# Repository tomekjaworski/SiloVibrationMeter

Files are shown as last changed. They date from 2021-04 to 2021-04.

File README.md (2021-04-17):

# SiloVibrationMeter
Urządzenie do pomiaru wibracji powierzchniowych konstrukcji silosów

Urządzenie przeznaczone jest do pomiarów wibracji powierzchni silosów w konstrukcjach stalowych. Wibracje mierzone są w trzech osiach, za pomocą akcelerometrów i przekazywane do centralnego komputera.
Za kanał komunikacyjny wybrano UDP.

### Charakterystyka
  * Podstawa pomiarowa: trzy akcelerometry **ADXL001**, zasilanymi ze źródłeł napięcia referencyjnego **ADR3433ARJZ**.
  * Budowa jednego toru pomiarowego: programowalne źródło napięcia odniesienia **MCP4921** dla wzmacniacza Rail-to-Rail **MCP6S2** + **dwa** wspólne napięcia referencyjne (**REF02**).
  * Jednostka centralna: **dsPIC33FJ128MC706A** (16bit, architektura MIPS).
  * Komunikacja: kontroler ethernetowy **ENC28J60** z wbudowanym transformatorem separującym. Prędkośc komunikacji: **10Mbps**.
  * Obsługiwane protokoły: **UDP**, **IP**, **ARP**, **DHCP**, **ICMP**.
  * Metoda akwizycji danych: typu **Ping-Pong**, wykorzystująca wbudowany kontroler **DMA** (równoległa budowa nowej paczki pomiarów i wysyłanie już wcześniej zbudowane).

### Zdjęcia

Widok głównego okna aplikacji zbierającej dane z wielu urządzeń pomiarowych:
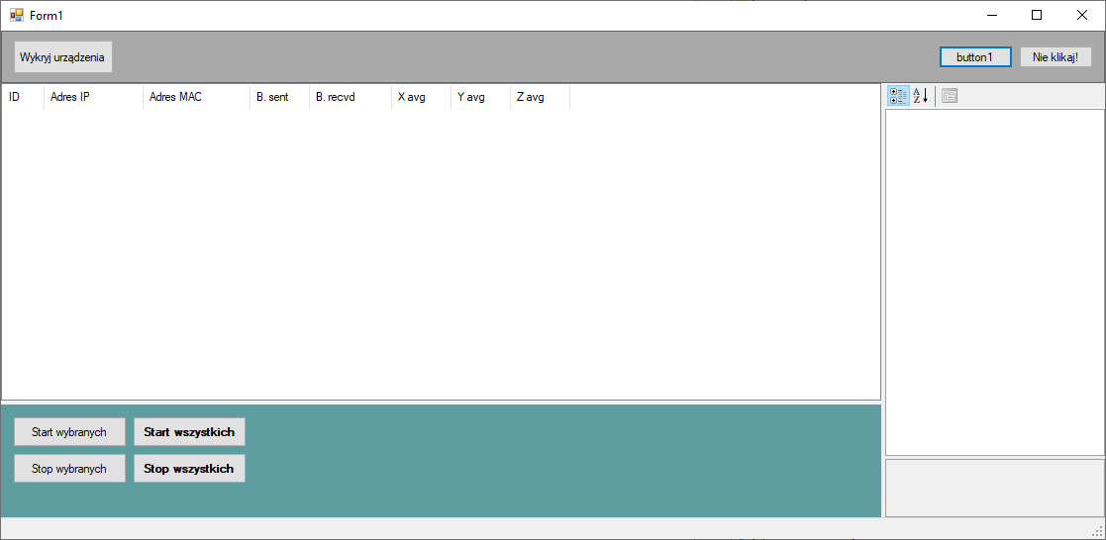
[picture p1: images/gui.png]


Prototyp pierwszy:
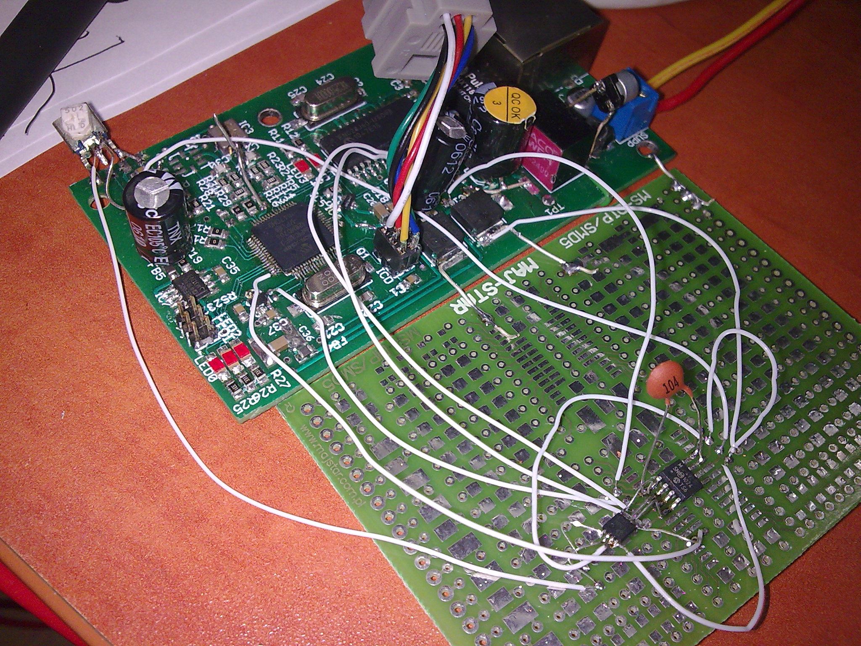
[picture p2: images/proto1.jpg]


Prototyp drugi:
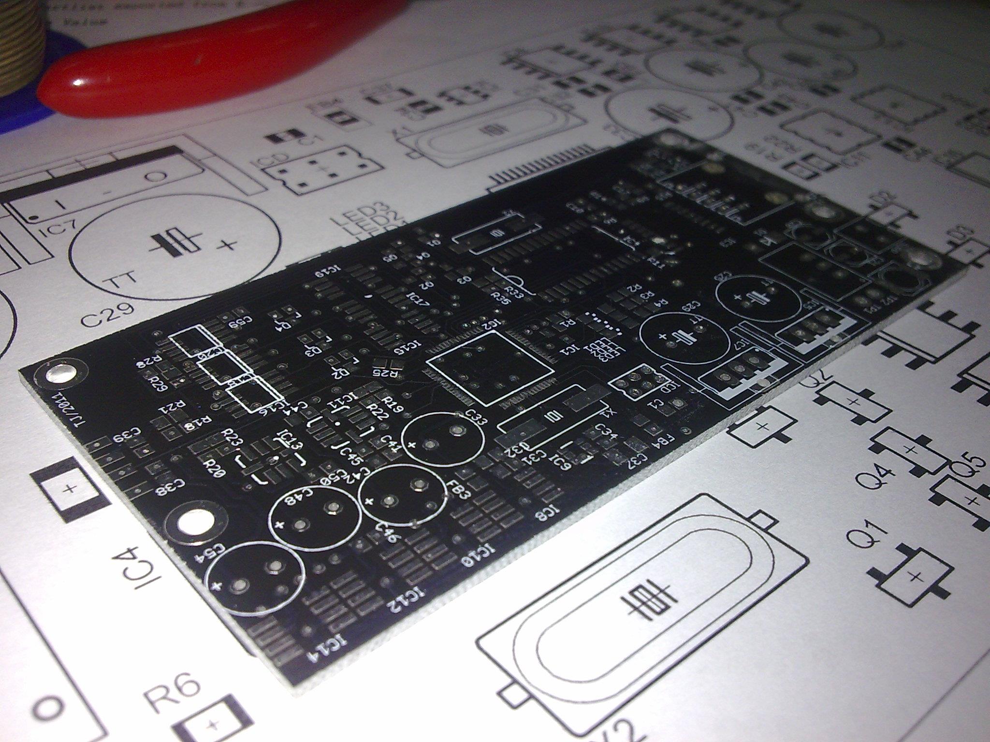
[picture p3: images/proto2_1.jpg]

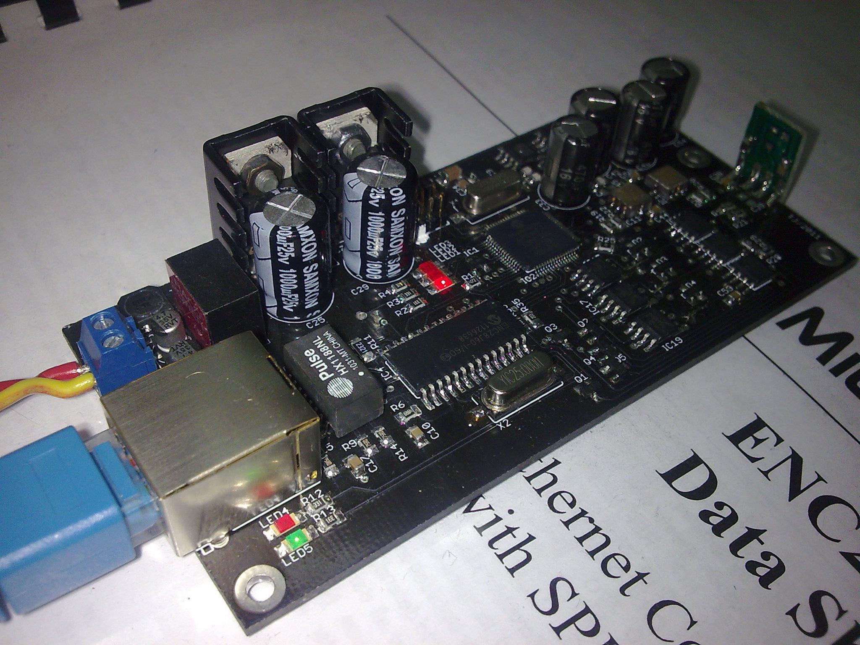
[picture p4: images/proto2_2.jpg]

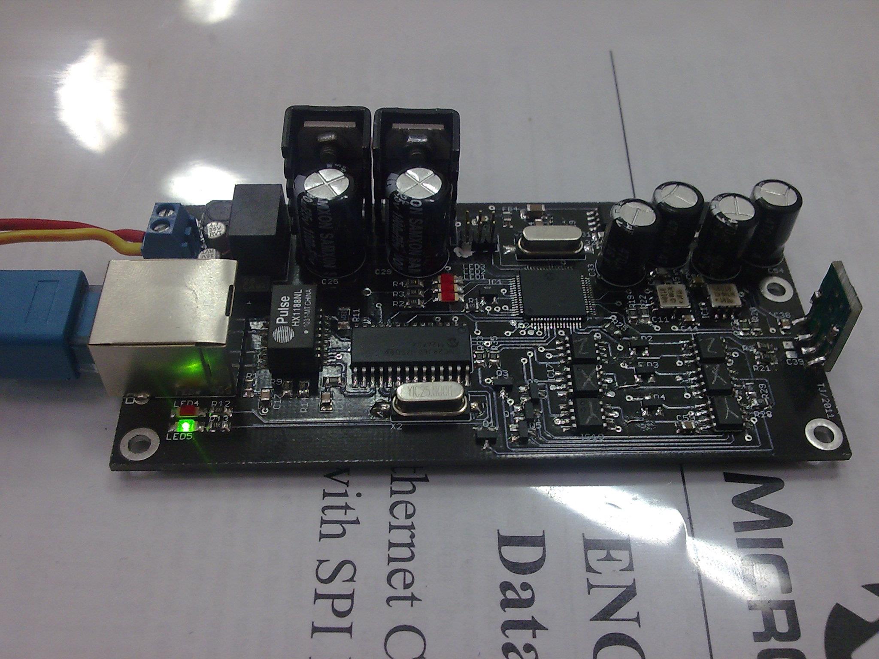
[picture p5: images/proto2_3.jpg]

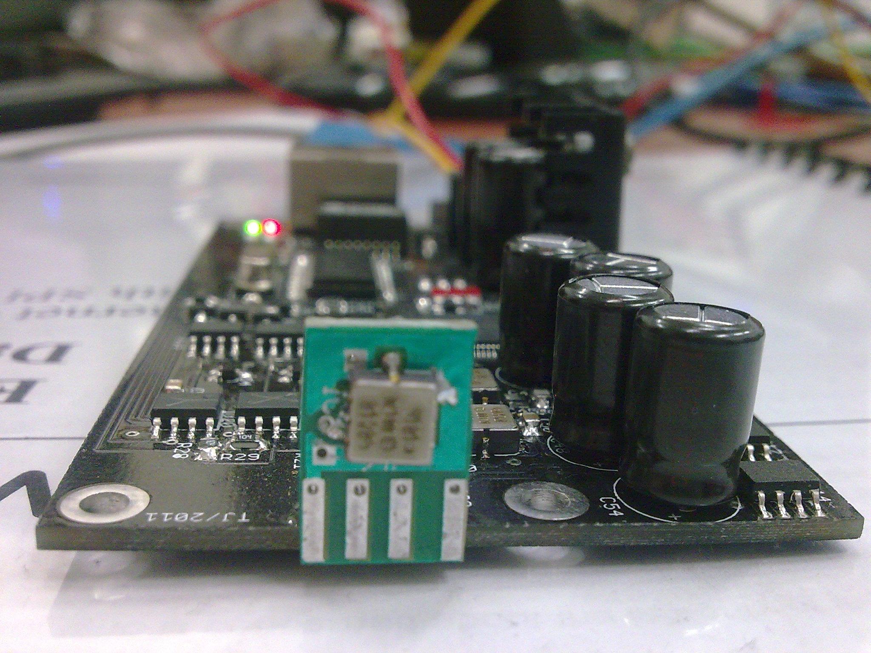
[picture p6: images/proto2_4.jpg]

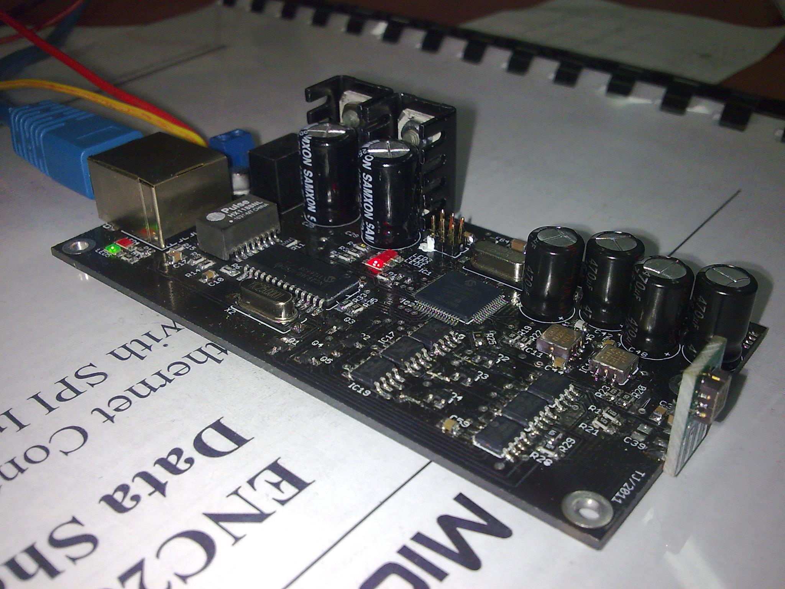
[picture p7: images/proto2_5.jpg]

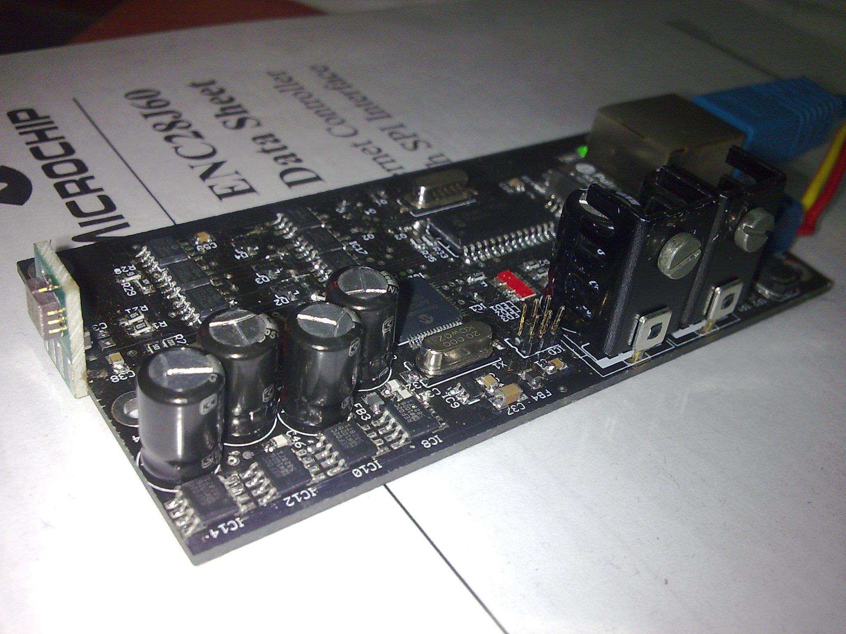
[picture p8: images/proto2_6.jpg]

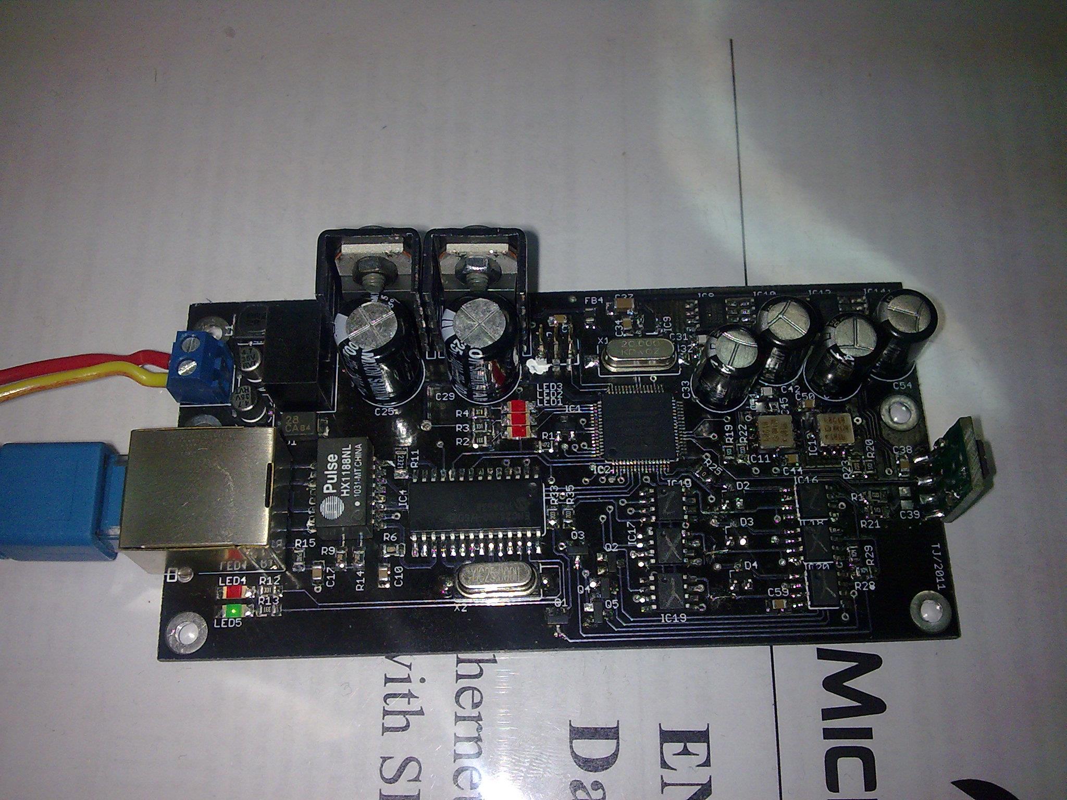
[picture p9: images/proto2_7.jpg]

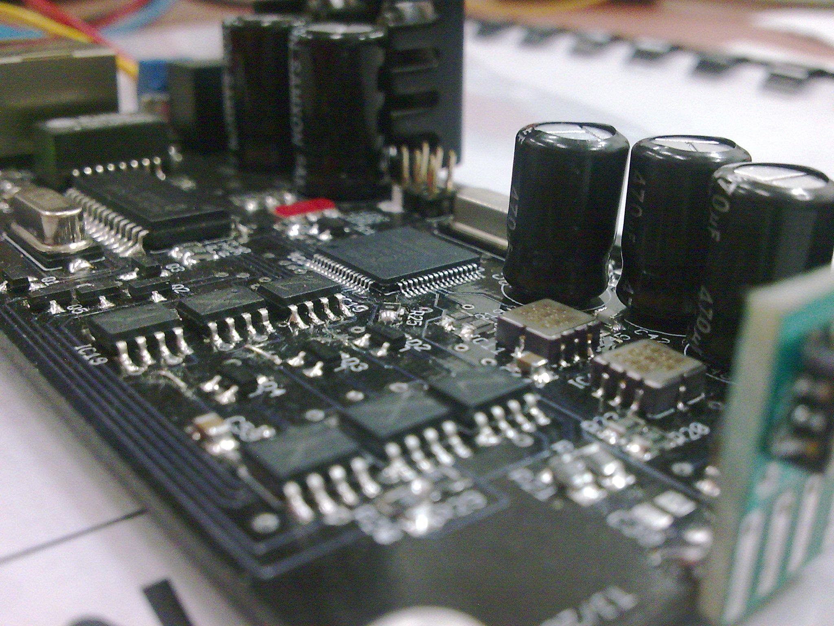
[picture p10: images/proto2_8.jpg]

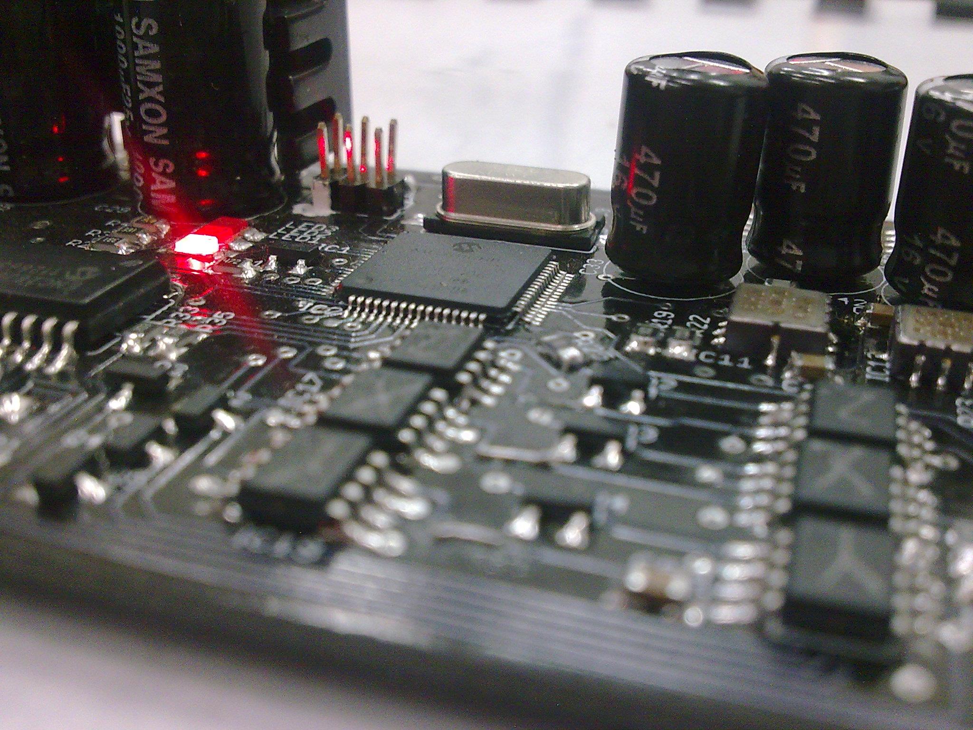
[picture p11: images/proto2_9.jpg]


Os pionowa:
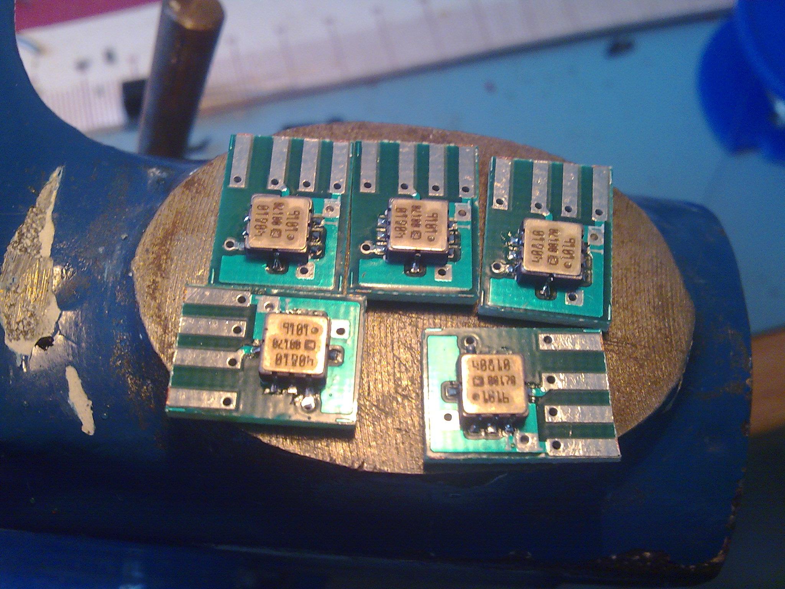
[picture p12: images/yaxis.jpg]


Testy prototypu drugiego:
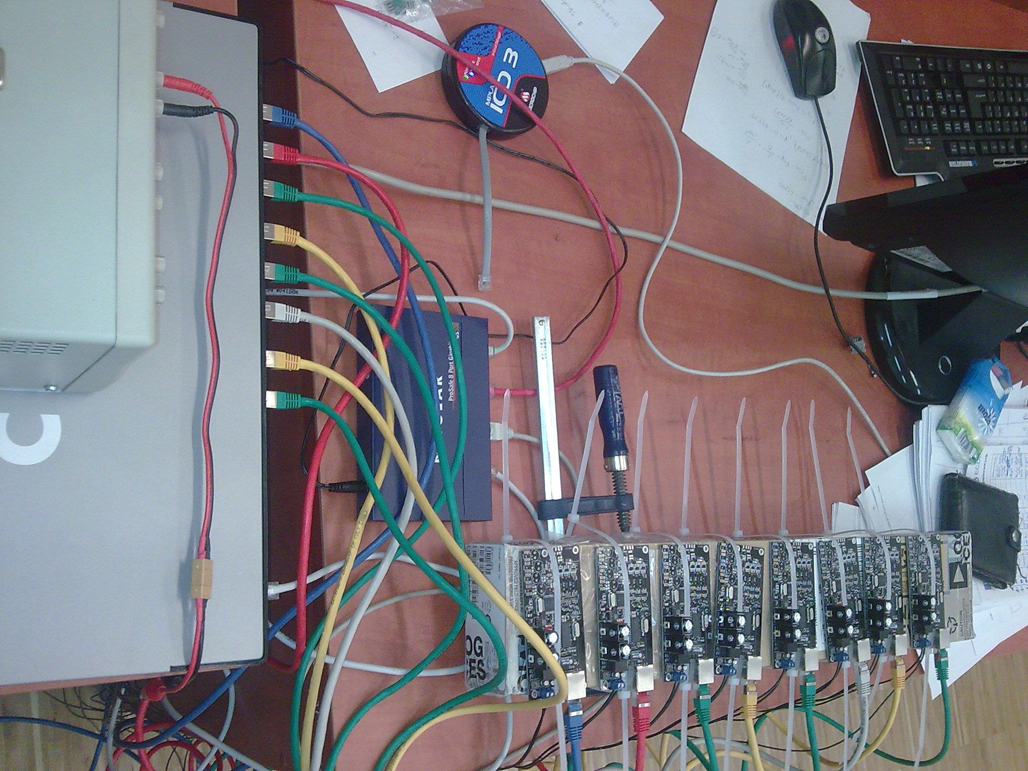
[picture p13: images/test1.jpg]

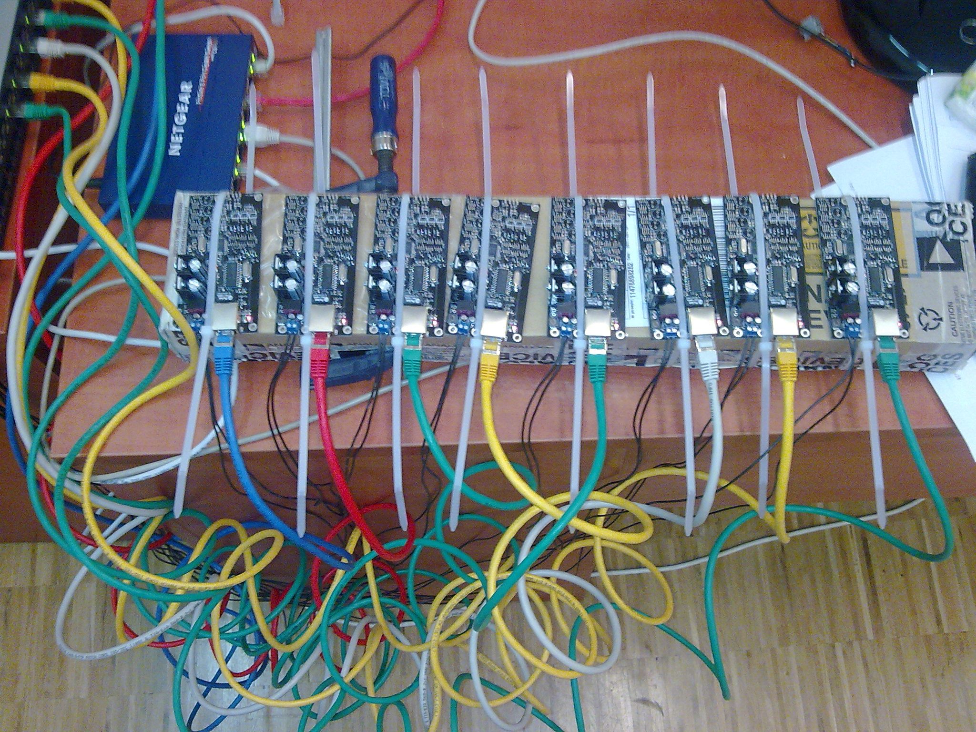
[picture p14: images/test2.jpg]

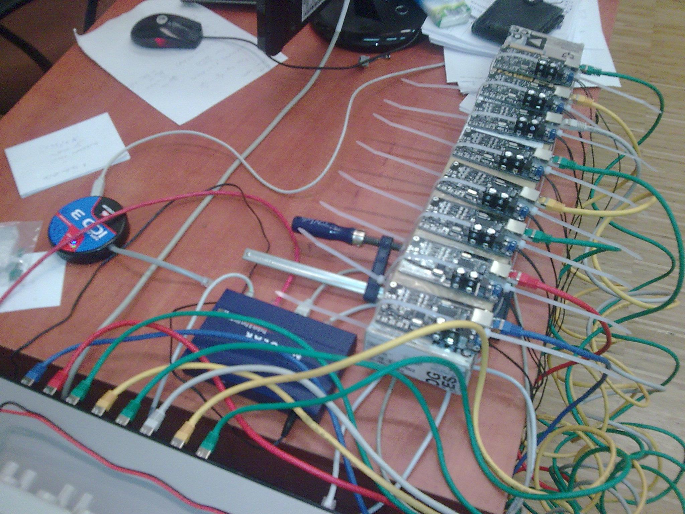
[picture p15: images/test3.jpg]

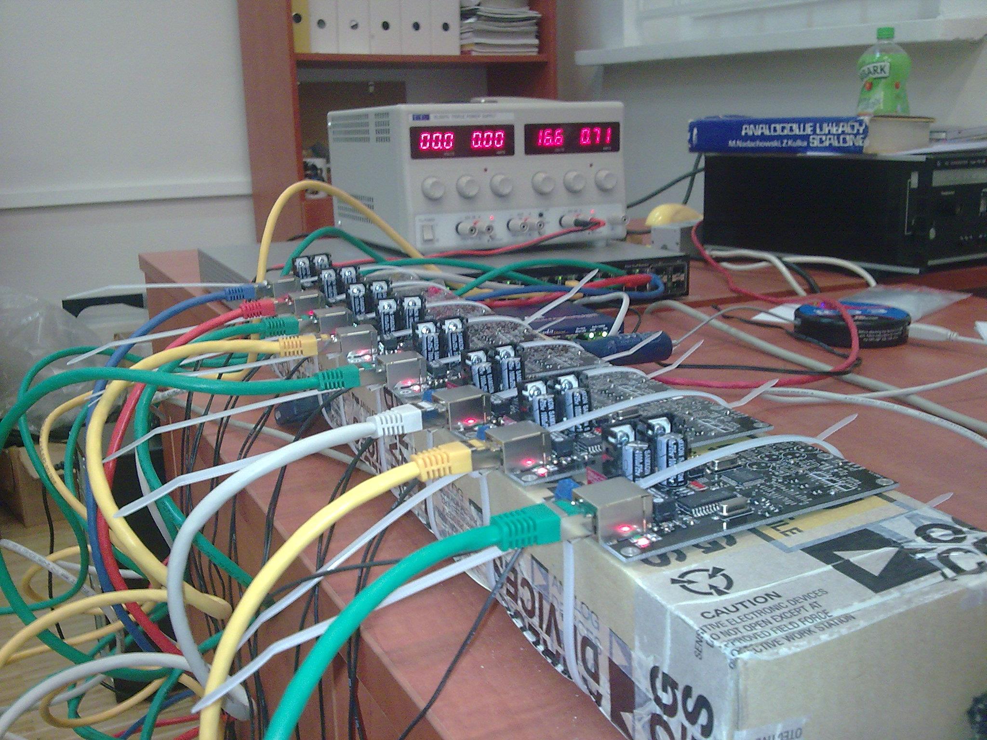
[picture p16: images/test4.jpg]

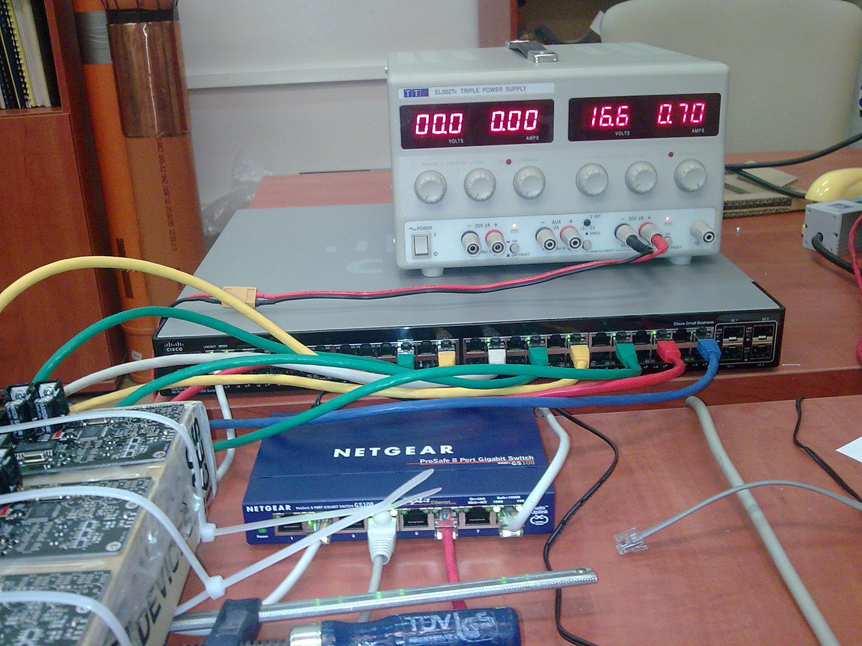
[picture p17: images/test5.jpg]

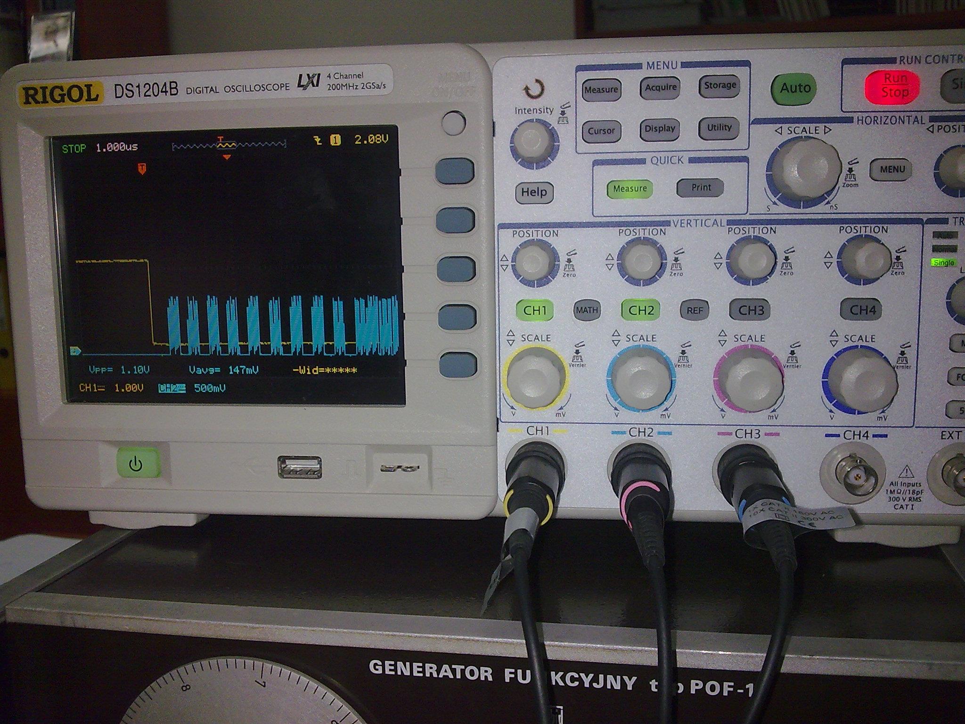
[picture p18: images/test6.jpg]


Ustawienia bitów w środowisku MPLAB:
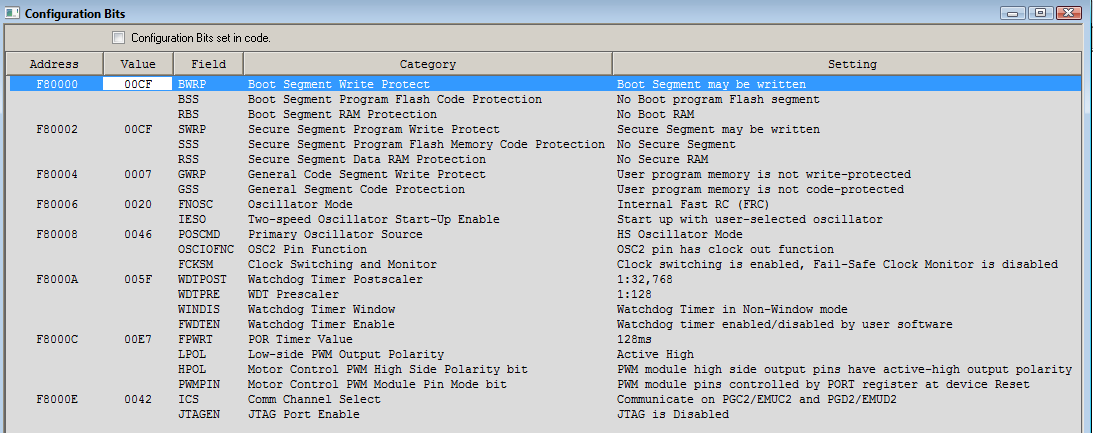
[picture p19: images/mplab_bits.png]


### Schematy
Blok CPU:
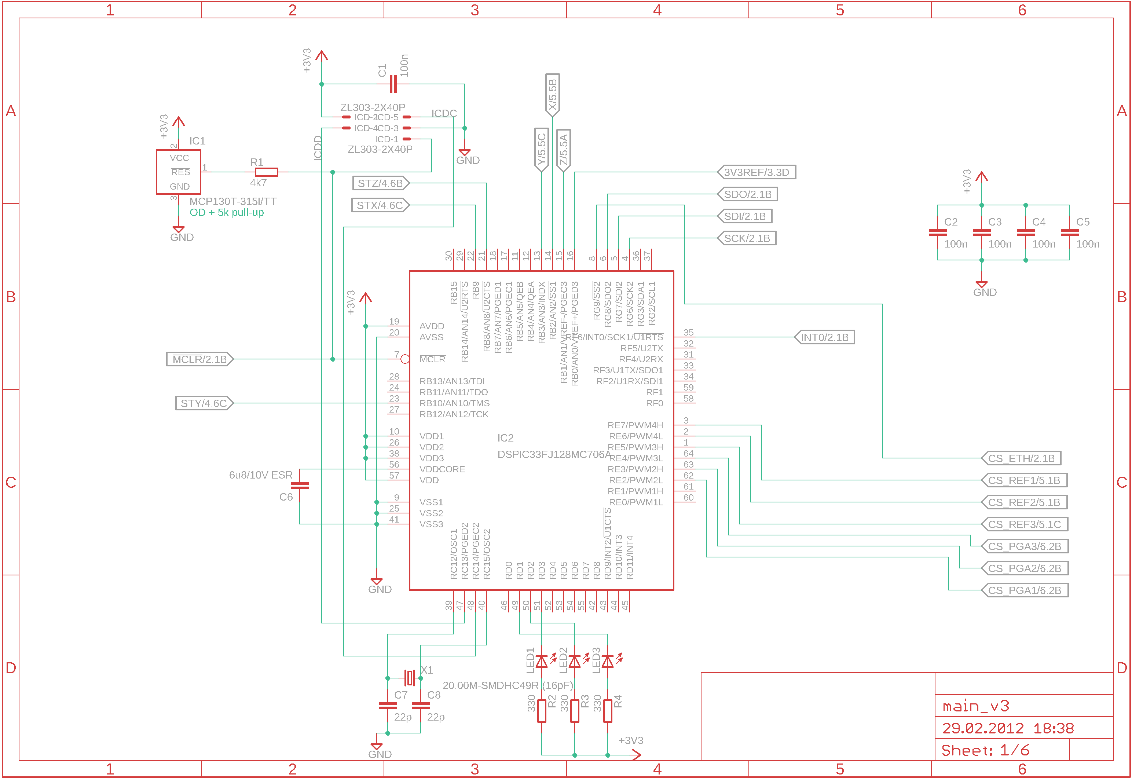
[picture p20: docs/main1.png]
Blok CPU

Interfejs sieciowy:
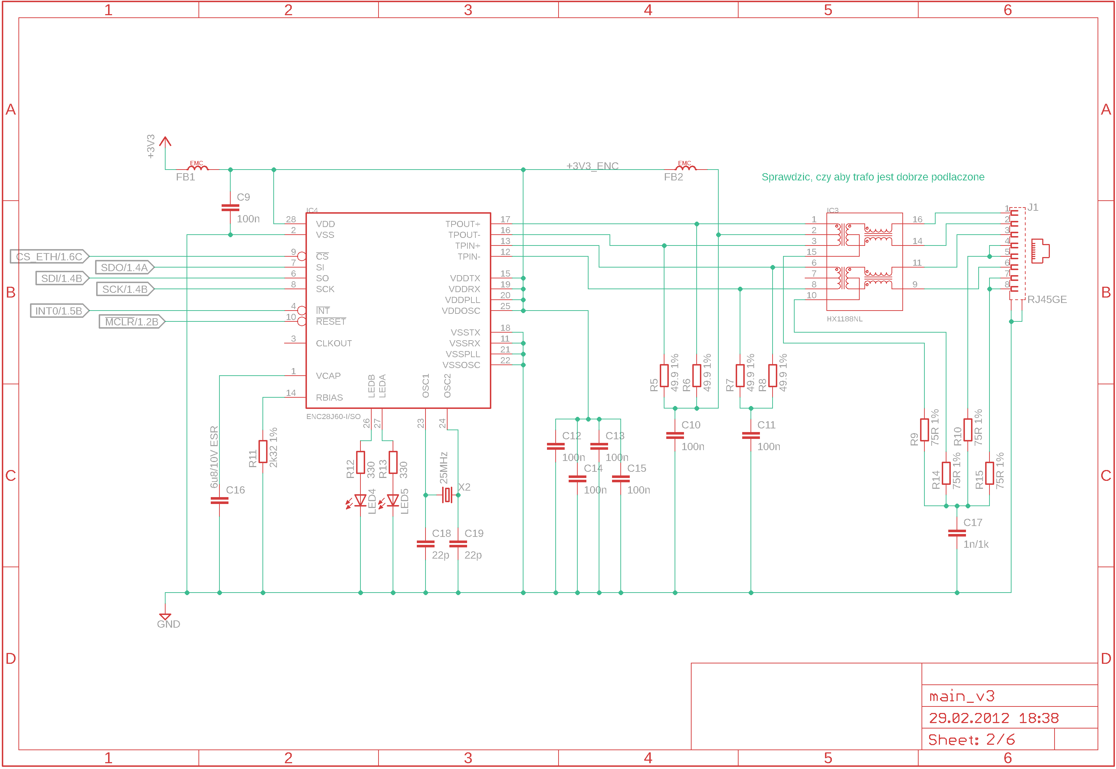
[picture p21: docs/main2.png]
Interfejs sieciowy

Zasilanie:
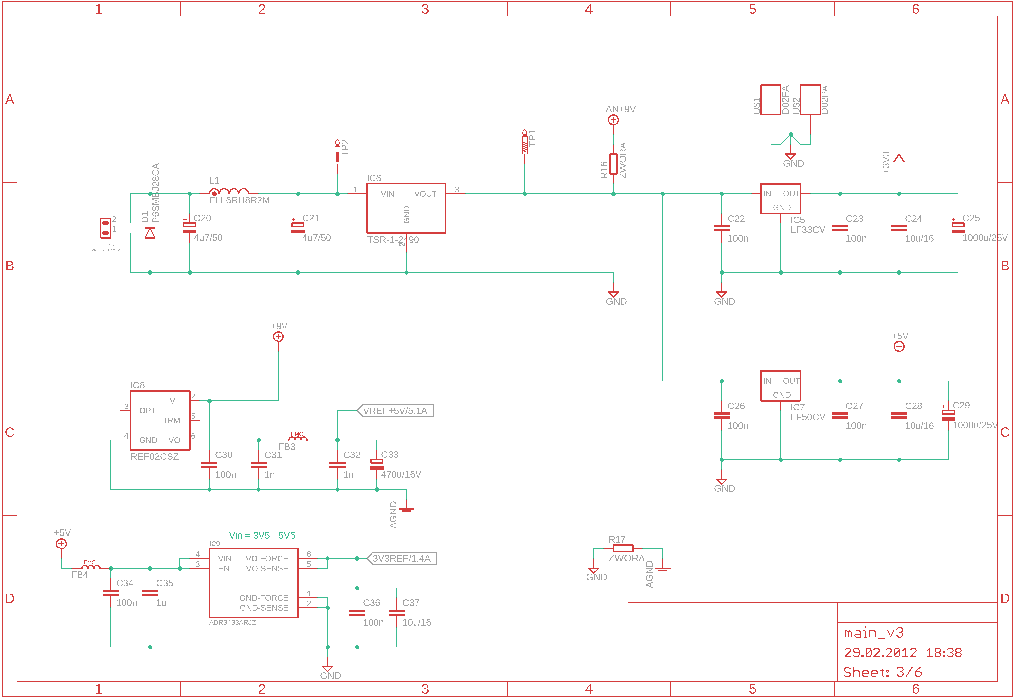
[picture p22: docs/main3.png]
Zasilanie

Akcelerometry i napięcie referencyjne:
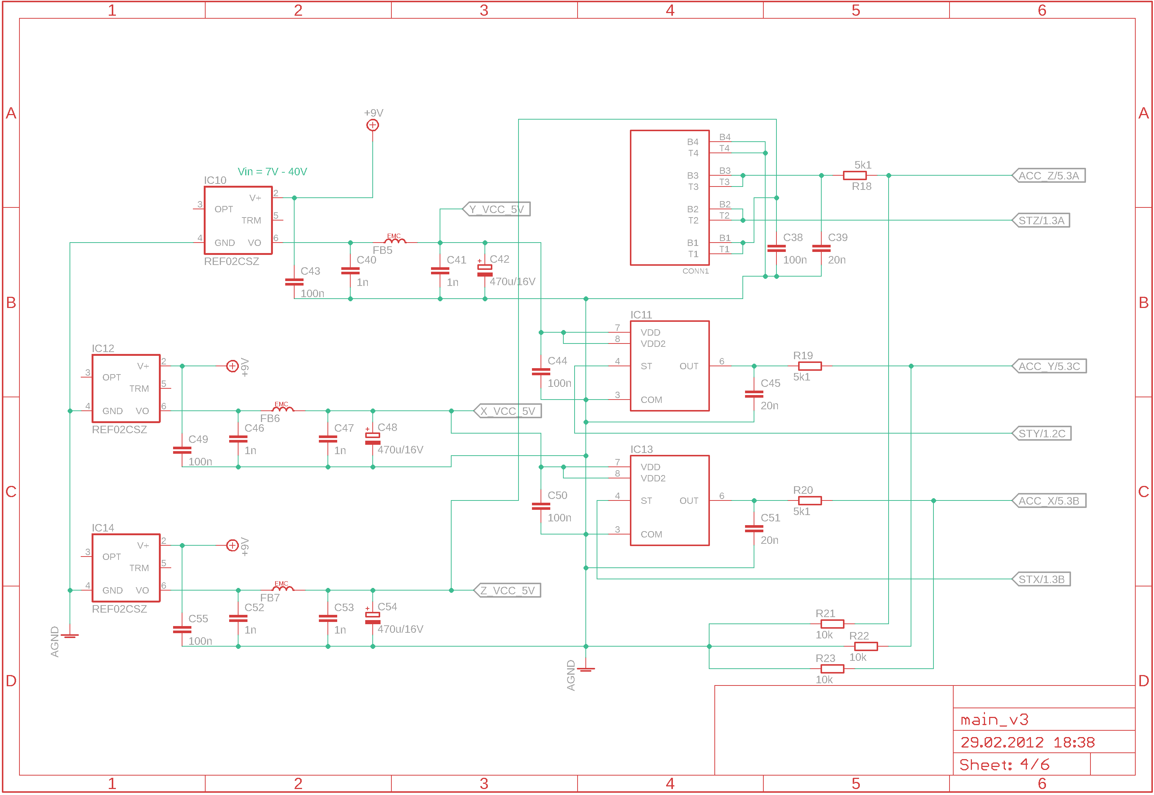
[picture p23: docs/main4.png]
Akcelerometry i napięcie referencyjne

Programowalne wzmacniacze:
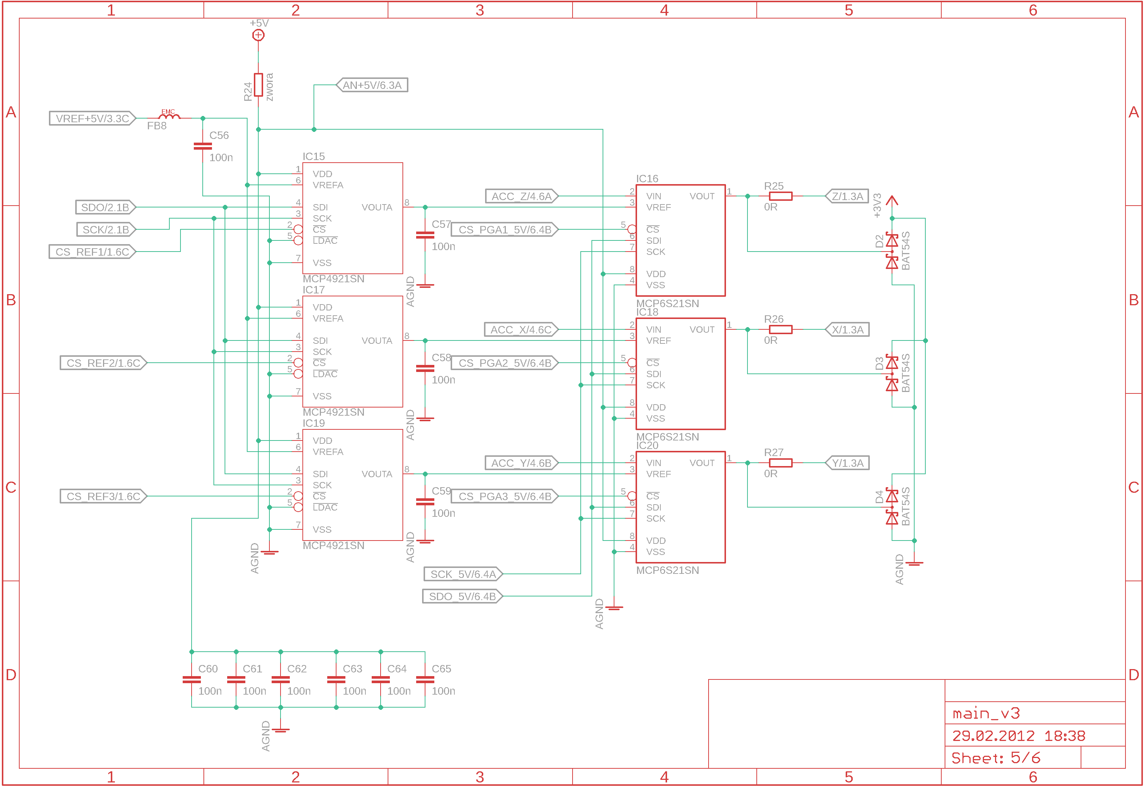
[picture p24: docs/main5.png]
Programowalne wzmacniacze

Konwerter poziomów 3V3 -> 5V:
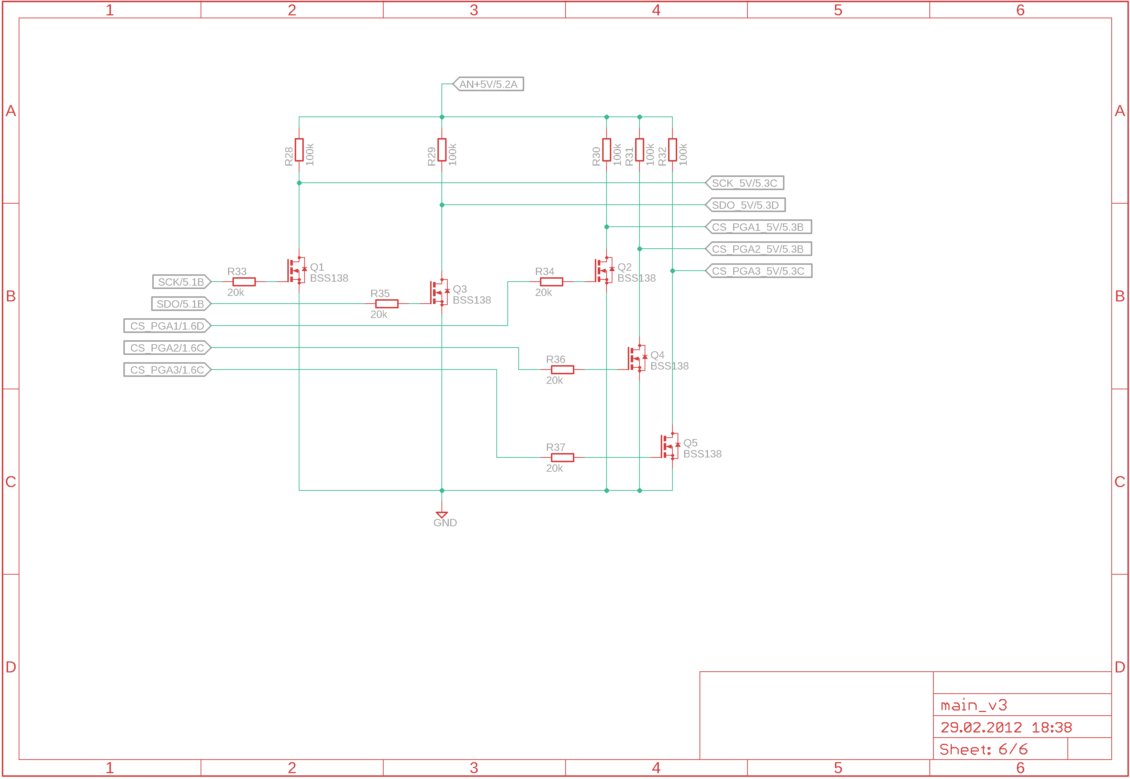
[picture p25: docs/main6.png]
Konwerter


Wersje PDF:
  * [Płyta główna - schemat](main_schemat.pdf)
  * [Płyta główna - PCB](docs/main_PCB.pdf)
  * [Moduł osi Z - schemat](osZ_inv.pdf)
  * [Moduł osi Z - PCB](osZ_inv_PCB.pdf )

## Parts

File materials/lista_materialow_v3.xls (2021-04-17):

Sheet: Arkusz1
Pozostało do zamówienia: | Zakupiono | miejsce | nazwa katalogowa | obudowa
0 | 12 | TME | P6SMBJ28CA | DO214AA | Dioda transil; 28V; 34,5V; 600W; dwukierunkowa; DO214AA
0 | 100 | TME | LCBB-601 | 0805 | Dławik:ferrytowy; Ferryt:koralik; 600R; 2A; SMD; 0805; R:100mΩ
0 | 400 | TME | CL21B104KBCNNNC | 0805 | Kondensator:ceramiczny; 100nF; 50V; X7R; ±10%; SMD; 0805; -55÷125°C
36 | 0 | TME | CSMD10U1206X | 1206 | Kondensator:ceramiczny; 10uF; 25V; X5R; ±10%; SMD; 1206
0 | 200 | TME | C0805C102J5GAC | 0805 | Kondensator:ceramiczny; 1nF; 50V; C0G (NP0); ±5%; SMD; 0805
0 | 100 | TME | C0805C105K8RAC | 0805 | Kondensator:ceramiczny; 1uF; 10V; X7R; ±10%; SMD; 0805; -55÷125°C
0 | 100 | TME | CL21C220JBANNNC | 0805 | Kondensator:ceramiczny; 22pF; 50V; C0G; ±5%; SMD; 0805; -55÷125°C
0 | 25 | TME | CE4.7/35-SMDHT |  | Kondensator:elektrolityczny; SMD; 4,7uF; 35V; Ø4x5,8mm; ±20%
0 | 25 | TME | TPSB685K016R120 | 1210 | Kondensator:tantalowy; 6,8uF; 16V; Obud:B; ESR:1200mΩ; ±10%; SMD
0 | 40 | TME | KPT-3216ID | 1206 | LED SMD; 1206; czerwony; 5-12mcd; 120°
0 | 30 | TME | KPT-3216SGD | 1206 | LED SMD; 1206; zielony; 3-12mcd; 120°
0 | 12 | TME | 33FJ128M706AIPT | TQFP64 | Mikrokontroler dsPIC; Pamięć programu:128kB; SRAM:16384B
0 | 12 | TME | 25.00M-SMDHC49S | SMD | Rezonator:kwarcowy; SMD; 25MHz
0 | 12 | TME | 20.00M-SMDHC49R | SMD | Rezonator:kwarcowy; SMD; Obud:HC49SM; 20MHz; Tolerancja:±30ppm
0 | 100 | TME | M0.6W-2K32 | THT | Rezystor:metal film; THT; 2,32kΩ; 0,6W; ±1%; Ø2,5x6,8mm; 50ppm/°C
72 | 0 | TME | SMD0805-0R | 0805 | Rezystor:thick film; SMD; 0805; 0R; 0,125W; ±5%; -55°C÷125°C
0 | 100 | TME | SMD0805-330R | 0805 | Rezystor:thick film; SMD; 0805; 330R; 0,125W; ±5%; -55÷125°C
0 | 100 | TME | SMD0805-4K7 | 0805 | Rezystor:thick film; SMD; 0805; 4,7kΩ; 0,125W; ±5%; -55°C÷125°C
48 | 0 | TME | SMD0805-75R-1% | 0805 | Rezystor:thick film; SMD; 0805; 75R; 0,125W; ±1%; -55°C÷125°C
0 | 100 | TME | SMD0805-49R9-1% | 0805 | Rezystor:thick film; SMD; 0805; 49,9R; 0,125W; ±1%; -55÷125°C
0 | 12 | TME | LF33CV | TO220 | Stabilizator napięcia:LDO,nieregulowany; 500mA; 3,3V; TO220
0 | 12 | TME | LF50CV | TO220 | Stabilizator napięcia:LDO,nieregulowany; 1000mA; 5V; TO220
0 | 12 | TME | HX1188NL |  | Transformator:LAN; SMD; -1dB; Przekładnia:RX 1:1,TX 1:1
0 | 12 | TME | MCP130T-315I/TT | SOT23 | Układ nadzorujący; open-drain; 3,15 V; Aktywny stan:niski; SOT23
0 | 12 | TME | ENC28J60-I/SO | SO28 | Układ scalony:kontroler ethernet; 10Base-T; SPI; SO28
0 | 48 | TME | REF02CSZ | SO8 | Źródło napięcia odniesienia; 5V; ±0,1% 8ppm; Montaż:SMD; SO8
27 | 21 | TME | KM470/16 | THT | Kondensator:elektrolityczny; THT; 470uF; 16V; Ø8x12mm; ±20%; 1000h
0 | 24 | TME | KM1000/25 | THT | Kondensator:elektrolityczny; THT; 1000uF; 25V; Ø10x16mm; ±20%
0 | 36 | TME | MCP4921-E/SN | SOIC8 | Przetwornik:D/A; 12bit; Kanały:1; SOIC8
23 | 13 | TME | MCP6S21-I/SN | SOIC8 | Układ scalony:wzmacniacz operacyjny; 2÷12MHz; SOIC8
0 | 24 | TME | D02PA | THT | Radiator:prasowany; U; TO202,TO220; 22K/W; czerniony; H:9,53mm
0 | 60 | TME | BSS138 | SOT23 | Tranzystor:unipolarny,N-MOSFET; 50V; 200mA; 360mW; SOT23
0 | 50 | TME | BAT54S | SOT23 | Dioda przełączająca Schottky; 30V; 10mA; 5ns; podwójna szeregowa
0 | 100 | TME | HP05-20K5% | 0805 | Rezystor:thick film; SMD; 0805; 20kΩ; 0,3W; ±5%; -55÷155°C
0 | 100 | TME | HP05-100K5% | 0805 | Rezystor:thick film; SMD; 0805; 100kΩ; 0,3W; ±5%; -55÷155°C
0 | 12 | TME | DG381-3.5-2P12 | 3.5mm THT | Listwa zaciskowa; kątowe; 1,5mm2; 3,5mm; THT,zaciski śrubowe
0 | 2 | TME | ZL303-2X40P | 2mm THT | Listwa kołkowa; kołkowe; męskie; PIN:80; proste; 2mm; THT; 2x40
0 | 12 | TME | RJ45GE | THT | Złącze:RJ45; gniazdo; PIN:8; ekranowane; THT; Układ wypr:8p8c
0 | 100 | TME | SMD0805-10K-1% | 0805 | Rezystor:thick film; SMD; 0805; 10kΩ; 0,125W; ±1%; -55÷125°C
0 | 100 | TME | SMD0805-5K1-1% | 0805 | Rezystor:thick film; SMD; 0805; 5,1kΩ; 0,125W; ±1%; -55÷125°C
0 | 12 | FARNEL | 1843663 | 6SOT23 | IC, NAPIĘCIE ODNIESIENIA, 3.3V, 6SOT23
0 | 12 | FARNEL | 1198594 |  | Inductance:8.2µH; Inductance Tolerance:± 20%; DC Resistance Max:0.087ohm; DC Current Rating:1.2A; Inductor Case Style:SMD; No. of Pins:2; SVHC:No SVHC (18-Jun-2010); DC Current Max:1.2A;
0 | 12 | FARNEL | 1696322 | TO220 | TRACOPOWER - TSR 1-2490 - CONVERTER, DC/DC, 24V/9V, 1A, SIP
0 | 15 | FARNEL | 1855318 | 0805 | KEMET - C0805X102KDRACTU - CAPACITOR, 0805, 1000V, 1NF
0 | 12 | FARNEL | 1162017 | TQFP64 | IC, 16BIT MCU/DSP 128K FLASH, SMD
0 | 50 | FARNEL | 1469987 | 1206 | OPORNIK, 1206, 2.32KR, 1%
 |  | Poniżej są trzy alternatywy, gdyby dane elementy nie były jeszcze dostępne w TME:
 |  | FARNELL | 9755322 | TO232 | IC, V REG LDO +3,3V, TO-220-3
 |  | FARNEL | 1564401 | SOIC28 | ETHERNET CONTROLLER W/SPI, 28SOIC
 |  | FARNEL | 9697098 | C | CAPACITOR, CASE C, 4.7UF, 50V
36 |  | FARNELL | 1886106 (http://pl.farnell.com/johanson-dielectrics/250r18x106kv4e/mlcc-1206-x5r-25-v-10uf/dp/1886106) | 1206 | Kondensator:ceramiczny; 10uF; 25V; X5R; ±10%; SMD; 1206
72 |  | FARNELL | 1469846RL (http://pl.farnell.com/vishay-draloric/crcw08050000z0ea/opornik-0805-0r-1-0-125w/dp/1469846RL) | 0805 | Rezystor:thick film; SMD; 0805; 0R; 0,125W; ±5%; -55°C÷125°C
48 |  | FARNELL | 1469955 (http://pl.farnell.com/vishay-draloric/crcw080575r0fkea/opornik-0805-75r-1/dp/1469955) | 0805 | Rezystor:thick film; SMD; 0805; 75R; 0,125W; ±1%; -55°C÷125°C
27 |  | FARNELL | 9692789 (http://pl.farnell.com/panasonic/eca1chg471/kondensator-470uf-16v/dp/9692789) | THT | Kondensator:elektrolityczny; THT; 470uF; 16V; Ø8x12mm; ±20%; 1000h
23 |  | FARNELL | 1332152 (http://pl.farnell.com/microchip/mcp6s21-i-sn/amp-pg-1ch-12-mhz-spi-smd-soic8/dp/1332152) | SOIC8 | Układ scalony:wzmacniacz operacyjny; 2÷12MHz; SOIC8
204 | 0 | TME | RI-HTSBGM2.5-84 |  | Tuleja dystansowa; mosiądz; M2,5x8; M2,5; 8mm; nikiel
204 | 0 | TME | M2.5X6/D7985 |  | Śruba; M2,5x6; Łeb:walcowy; Nacięcie:Phillips; cynk; PH1
204 | 0 | TME | B2.5/BN109 |  | Nakrętka; sześciokątna; M2,5; stal; Pokrycie:cynk; H:2mm
408 | 0 | TME | B2.5/BN726 |  | Podkładka; okrągła; M2,5; D=5mm; h=0,5mm; stal; Pokrycie:cynk
12 |  |  | CA6H-10K (http://www.tme.eu/html/PL/potencjometry-montazowe-acp-serii-ca6/ramka_282_PL_pelny.html) |  | Potencjometr:montażowy,stojący,węglowy; Seria:CA6H; 10kΩ; 100mW

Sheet: BOM
Qty | Value | Device | Parts
1 |  | RJ45GE | J1
2 |  | ADXL001-70 | IC3, IC4
6 |  | FERRITE_BEAD0805 | FB1, FB5, FB6, FB7, FB8, FB9
5 |  | LEDCHIPLED_1206 | LED0, LED1, LED2, LED3, LED4
4 | 0R | R-EU_M0805 | R35, R36, R37, R19
9 | 1k P | R-EU_M0805 | R20, R21, R22, R23, R24, R28, R29, R30, R31
7 | 1n | C-EUC0805 | C29, C30, C32, C33, C34, C54, C55
1 | 1n/1k | C-EUC0805 | C17
1 | 1u | C-EUC1206 | C36
1 | 2k32 1% | R-EU_0204/5 | R10
1 | 4k7 | R-EU_R0805 | R15
2 | 4u7/50 | CPOL-EUUD-5X5,8 | C39, C40
2 | 6u8/10V ESR | C-EUC1210 | C10, C23
3 | 10u/16 | C-EUC1206K | C20, C44, C47
1 | 20.00M-SMDHC49R (16pF) | CRYSTALHC49UP | Q1
5 | 20k | R-EU_M0805 | R38, R41, R44, R45, R46
4 | 22p | C-EUC0805 | C21, C22, C24, C25
1 | 25MHz | CRYSTALHC49UP | Q2
4 | 49.9 1% | R-EU_M0805 | R1, R2, R3, R4
4 | 75R 1% | R-EU_R0805 | R6, R7, R8, R9
5 | 100k | R-EU_M0805 | R47, R50, R53, R54, R55
33 | 100n | C-EUC0805 | C1, C2, C3, C4, C5, C6, C7, C8, C9, C11, C12, C13, C14, C15, C16, C18, C19, C26, C27, C28, C31, C35, C37, C38, C41, C42, C43, C45, C50, C51, C52, C53, C56
5 | 330 | R-EU_R0805 | R11, R12, R25, R26, R27
2 | 470u/16V | CPOL-EUE3.5-8 | C49, C57
2 | 1000u/25V | CPOL-EUTT5D10 | C46, C58
1 | 87758-0616 | 87758-0616 | ICD
1 | ADR3433ARJZ | ADR3433ARJZ | IC9
3 | BAT54S | BAT54S | D1, D3, D4
5 | BSS138 | BSS123 | Q3, Q6, Q9, Q10, Q11
1 | DG381-3.5-2P12 | DG318-3.5-2P | SUPP
1 | DSPIC33FJ128MC706A | DSPIC33FJ128MC706 | IC5
1 | ELL6RH8R2M | ELL6RH8R2M | L1
1 | ENC28J60-I/SO | ENC28J60-I/SO | IC1
1 | HX1188NL | HX1188NL | IC2
1 | LF33CV | 78XXS | IC6
1 | LF50CV | 78XXS | IC13
3 | MCP6S21SN | MCP6S21SN | IC15, IC17, IC18
1 | MCP130T-315I/TT | MCP10T | IC12
3 | MCP4921SN | MCP4921SN | IC8, IC11, IC14
1 | P6SMBJ28CA | DIODE-DO214AA | D2
2 | REF02CSZ | REF02D | IC7, IC19
1 | TSR-1-2490 | TSR-1-2490 | IC10

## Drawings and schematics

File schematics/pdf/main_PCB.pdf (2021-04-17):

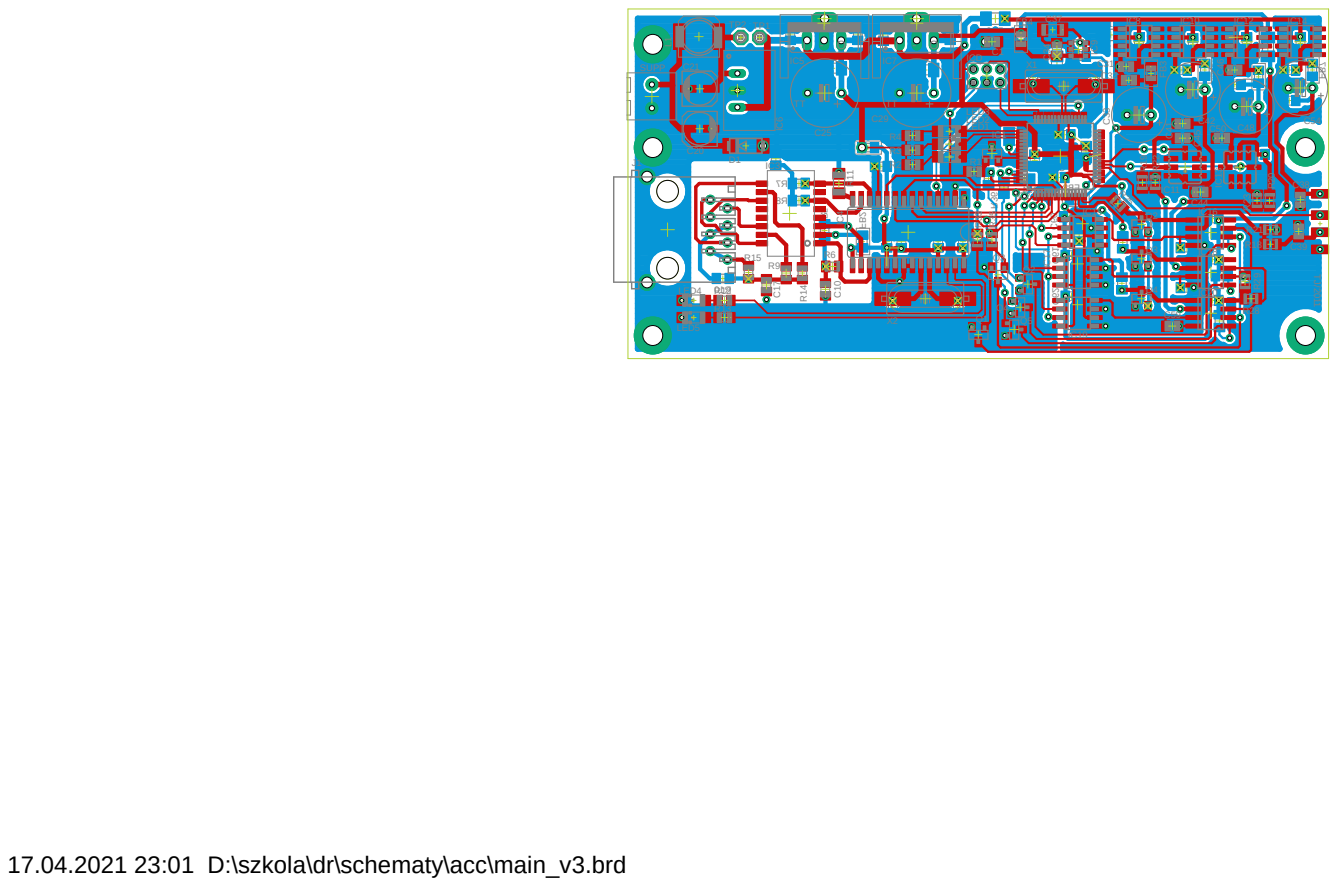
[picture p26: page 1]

SUPP | C21 | C1 ICD X1

X2 Q1 LED5 | Q5

17.04.2021 23:01 D:\szkola\dr\schematy\acc\main_v3.brd

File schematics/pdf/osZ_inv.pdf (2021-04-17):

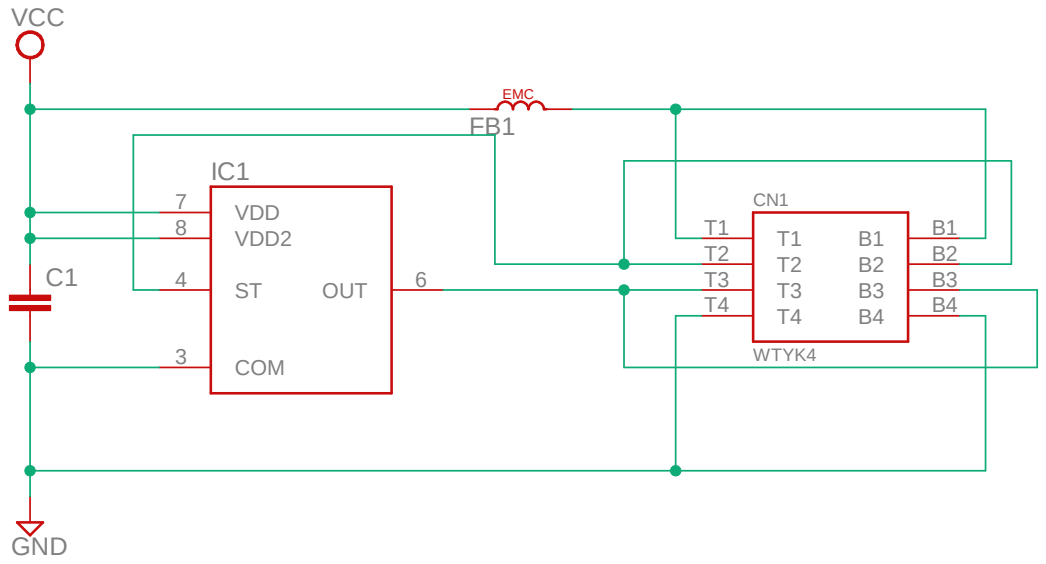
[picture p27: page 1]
Akcelerometr osi Z; GND; VCC; VDD 7 VDD2 8; COM 3; OUT; WTYK4; EMC

17.04.2021 22:59 D:\szkola\dr\schematy\acc\osZ_inv.sch (Sheet: 1/1)

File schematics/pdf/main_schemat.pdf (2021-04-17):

A

A

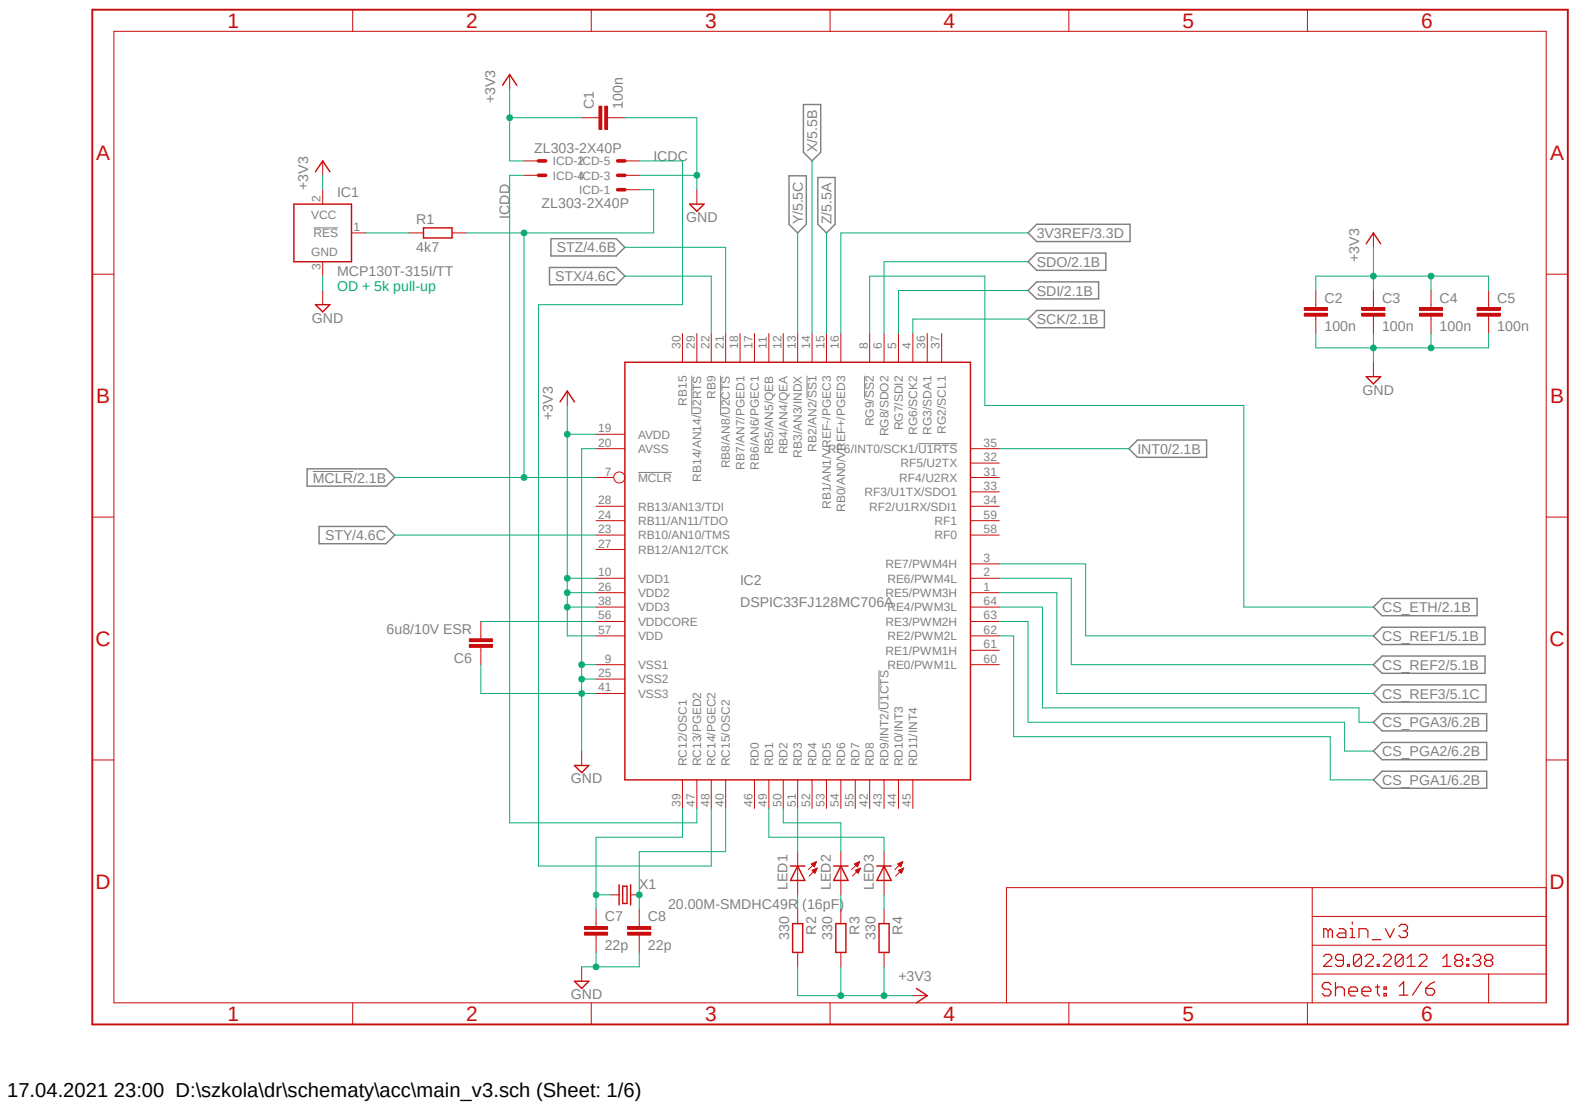
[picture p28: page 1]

VDD2 26
VDD3 38
VDDCORE 56
VDD 57

17.04.2021 23:00 D:\szkola\dr\schematy\acc\main_v3.sch (Sheet: 1/6)

A

A

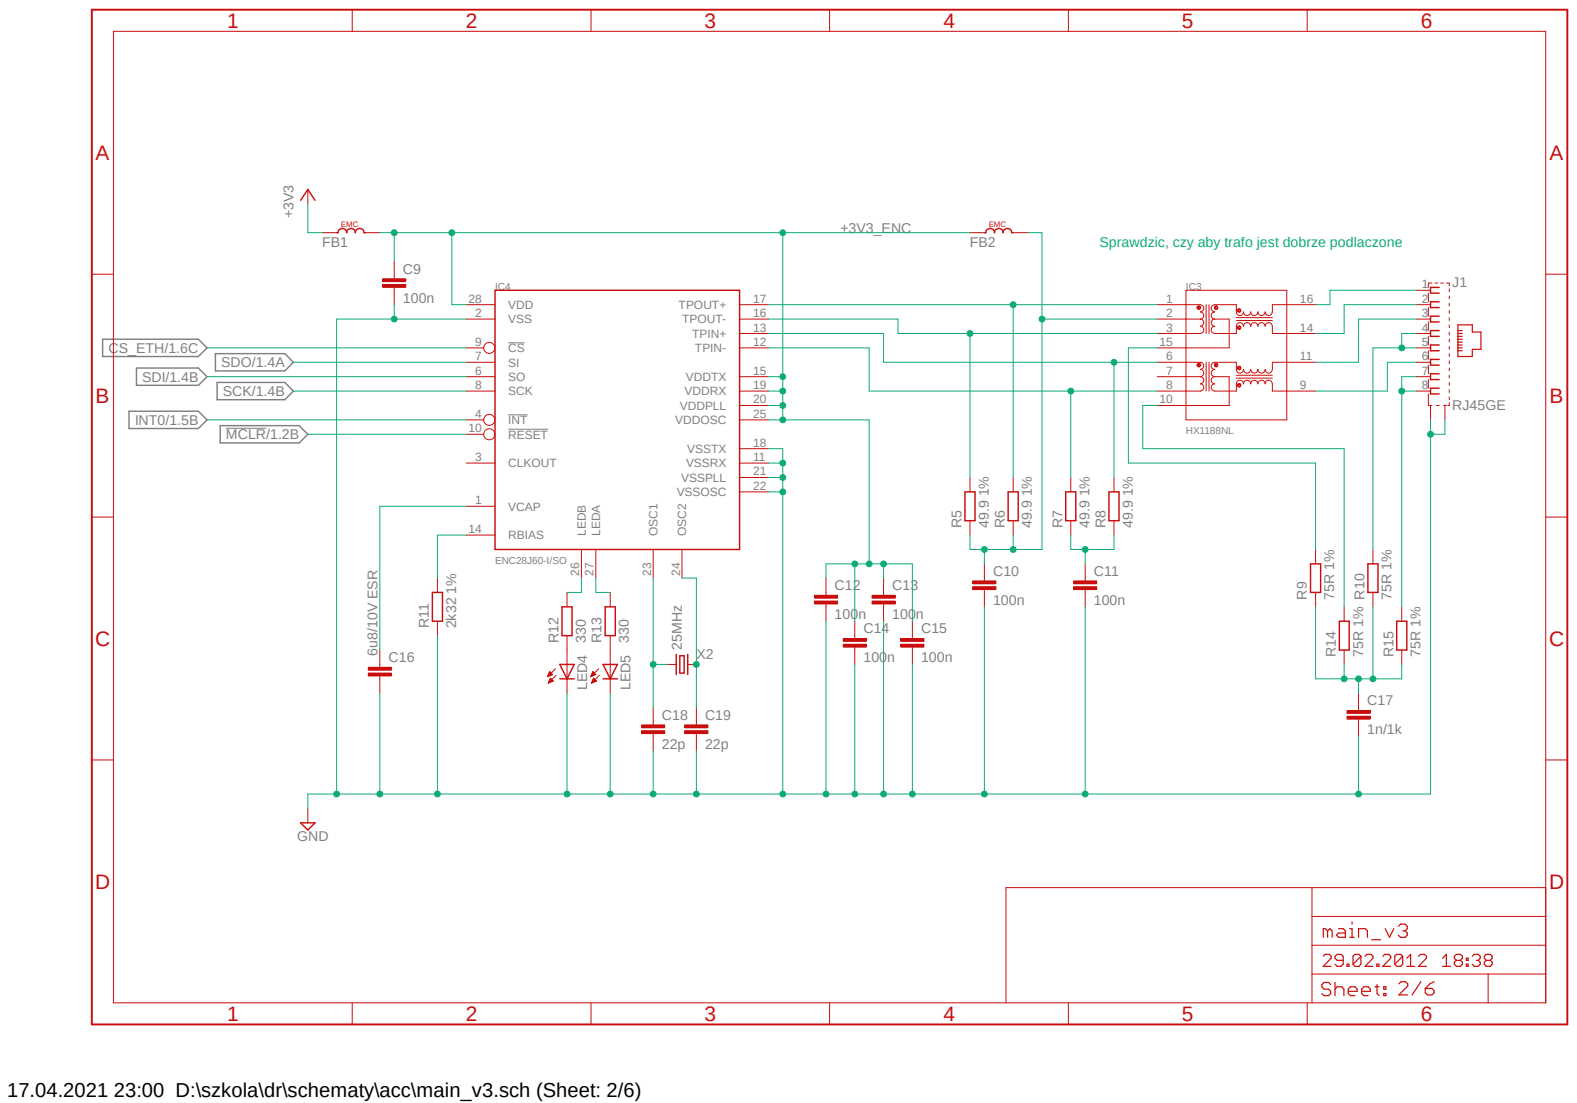
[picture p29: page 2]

Sprawdzic, czy aby trafo jest dobrze podlaczone

17.04.2021 23:00 D:\szkola\dr\schematy\acc\main_v3.sch (Sheet: 2/6)

A

A

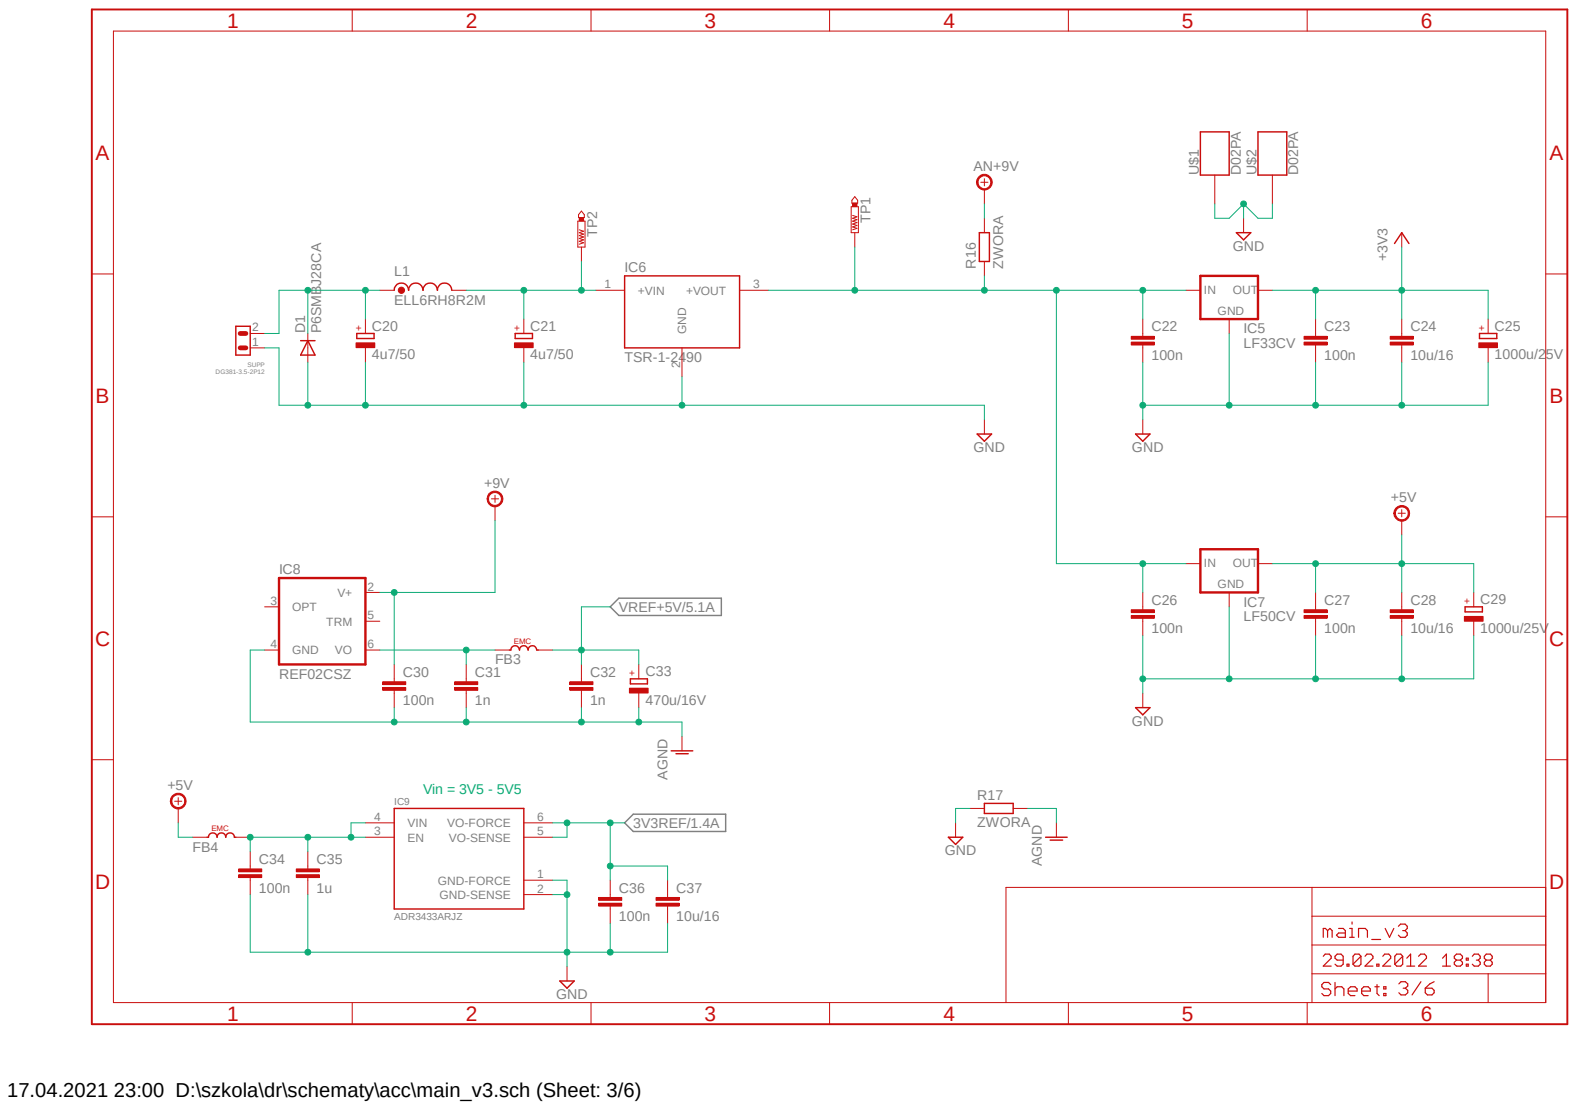
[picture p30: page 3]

17.04.2021 23:00 D:\szkola\dr\schematy\acc\main_v3.sch (Sheet: 3/6)

A

A

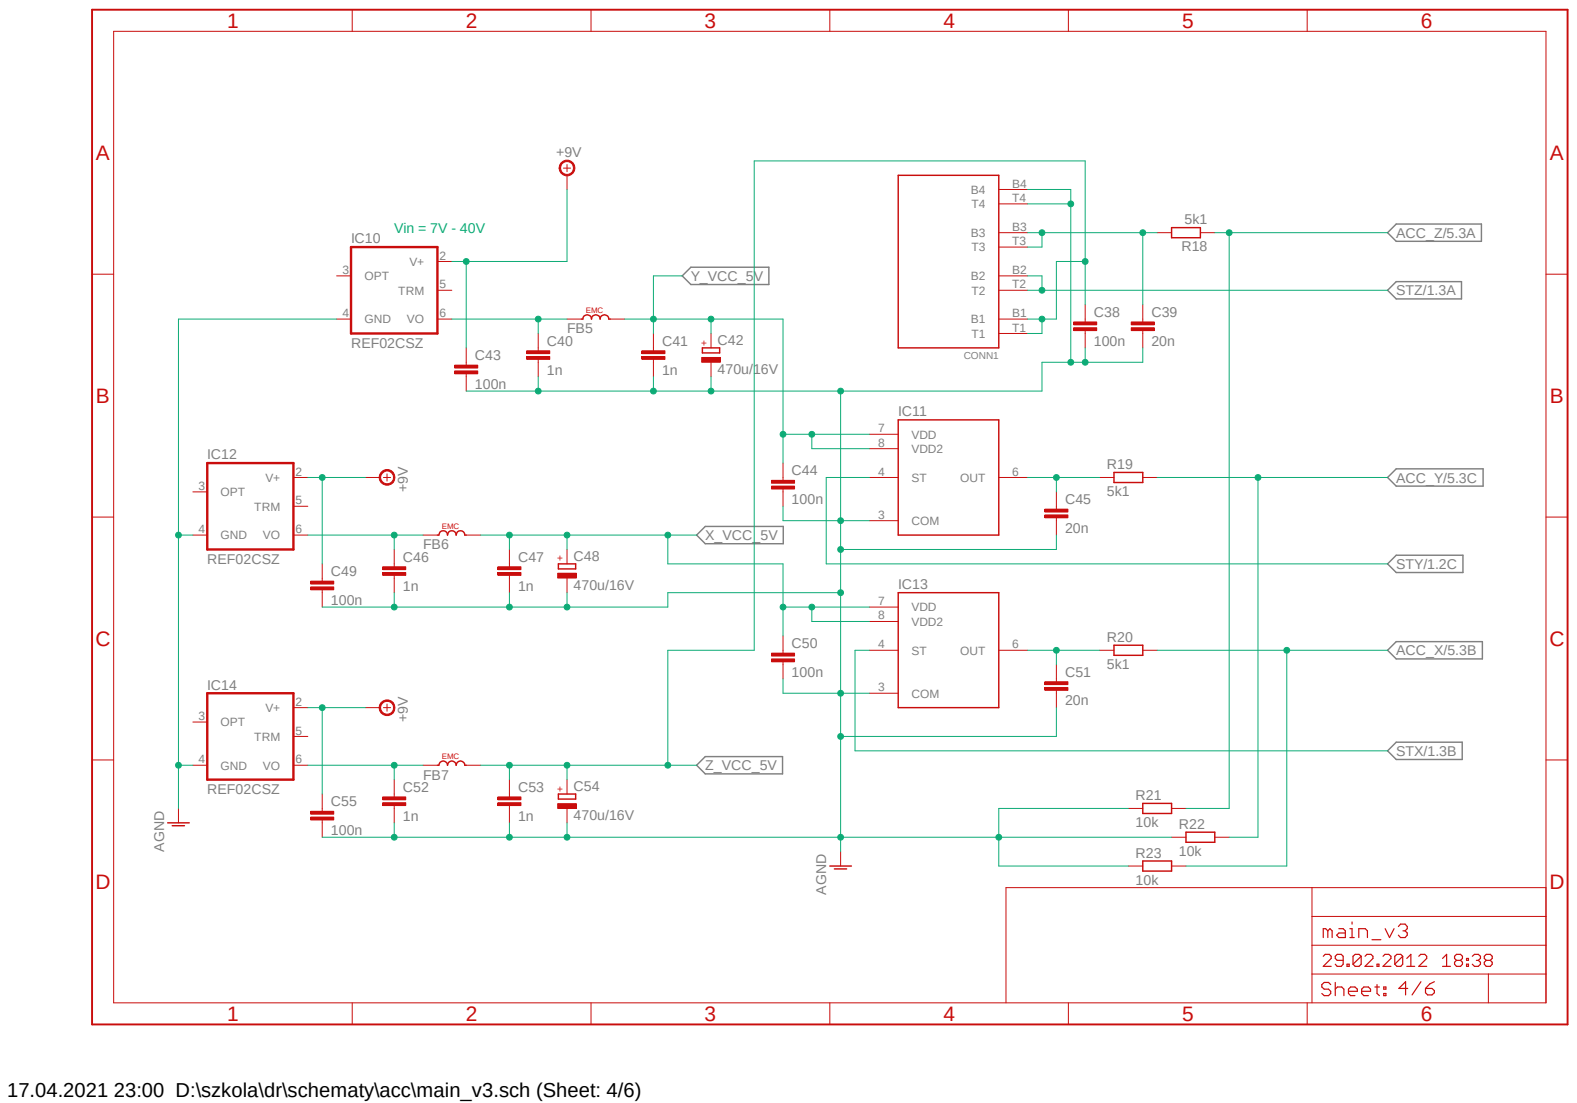
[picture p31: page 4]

VDD2 8

COM 3

17.04.2021 23:00 D:\szkola\dr\schematy\acc\main_v3.sch (Sheet: 4/6)

A

A

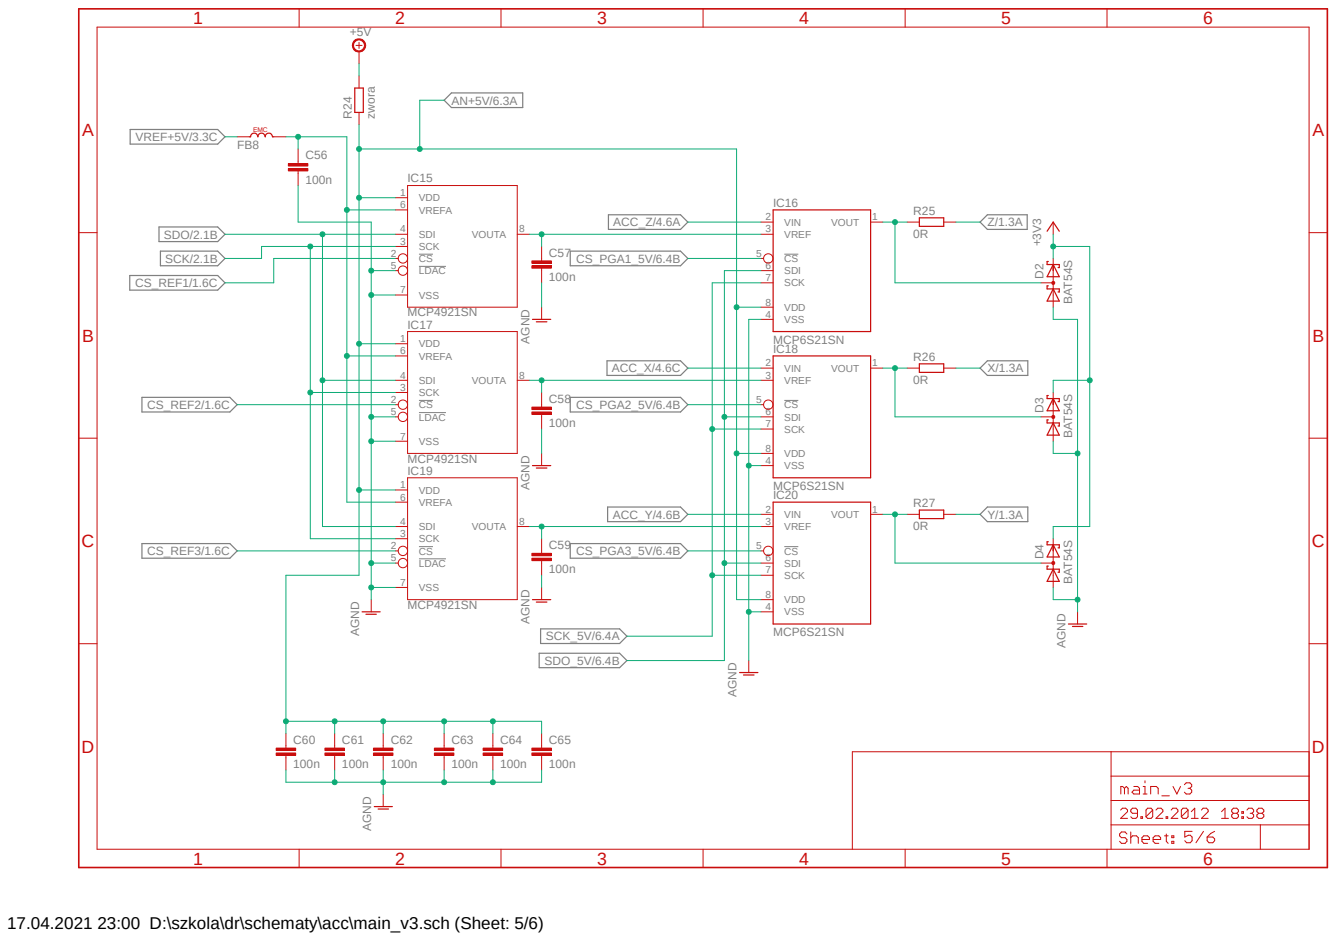
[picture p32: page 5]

AGND zwora SDI 4 SCK 3 CS 2 LDAC 5 VSS 7 VDD 1 VREFA 6 VOUTA 8 IC15SDI 4 SCK 3 CS 2 LDAC 5 VSS 7 VDD 1 VREFA 6 VOUTA 8 IC17SDI 4 SCK 3 CS 2 LDAC 5 VSS 7 VDD 1 VREFA 6 VOUTA 8 IC19 C56 FB8 C60 C61 C62 C57 C58 C59 VIN 2 VREF 3 CS 5 SDI 6 SCK 7 VSS 4 VDD 8 VOUT 1 IC16 MCP6S21SN VIN 2 VREF 3 CS 5 SDI 6 SCK 7 VSS 4 VDD 8 VOUT 1 IC18 MCP6S21SN VIN 2 VREF 3 CS 5 SDI 6 SCK 7 VSS 4 VDD 8 VOUT 1 IC20 MCP6S21SN C63 C64 C65 R25 R26 R27

17.04.2021 23:00 D:\szkola\dr\schematy\acc\main_v3.sch (Sheet: 5/6)

A

A

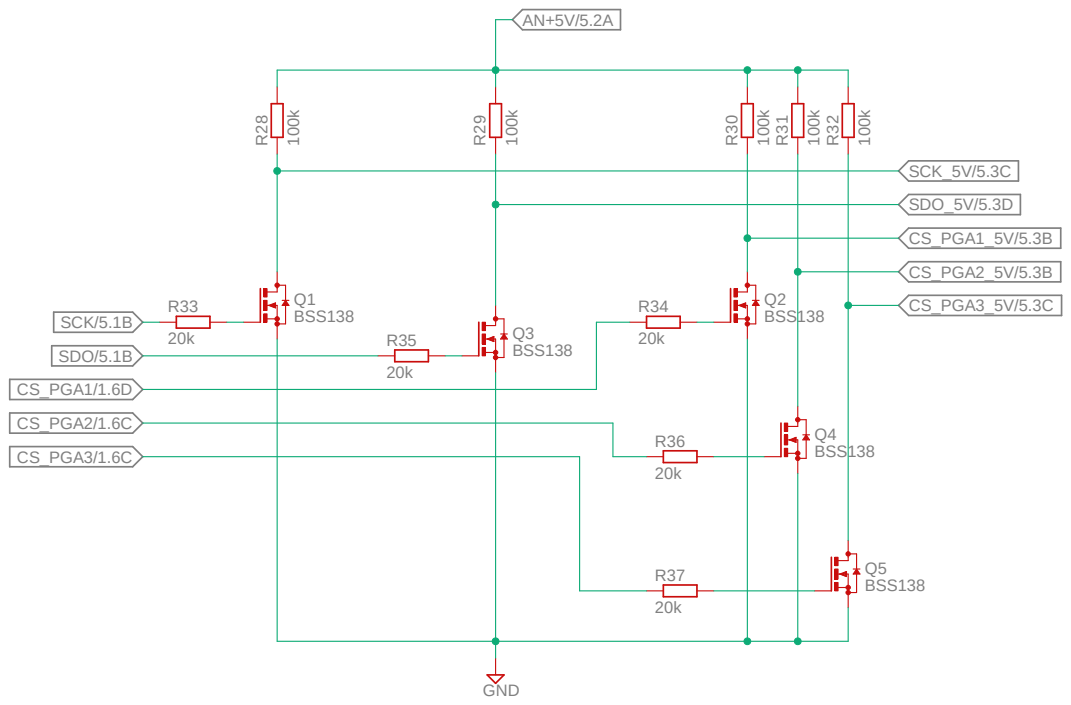
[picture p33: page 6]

17.04.2021 23:00 D:\szkola\dr\schematy\acc\main_v3.sch (Sheet: 6/6)

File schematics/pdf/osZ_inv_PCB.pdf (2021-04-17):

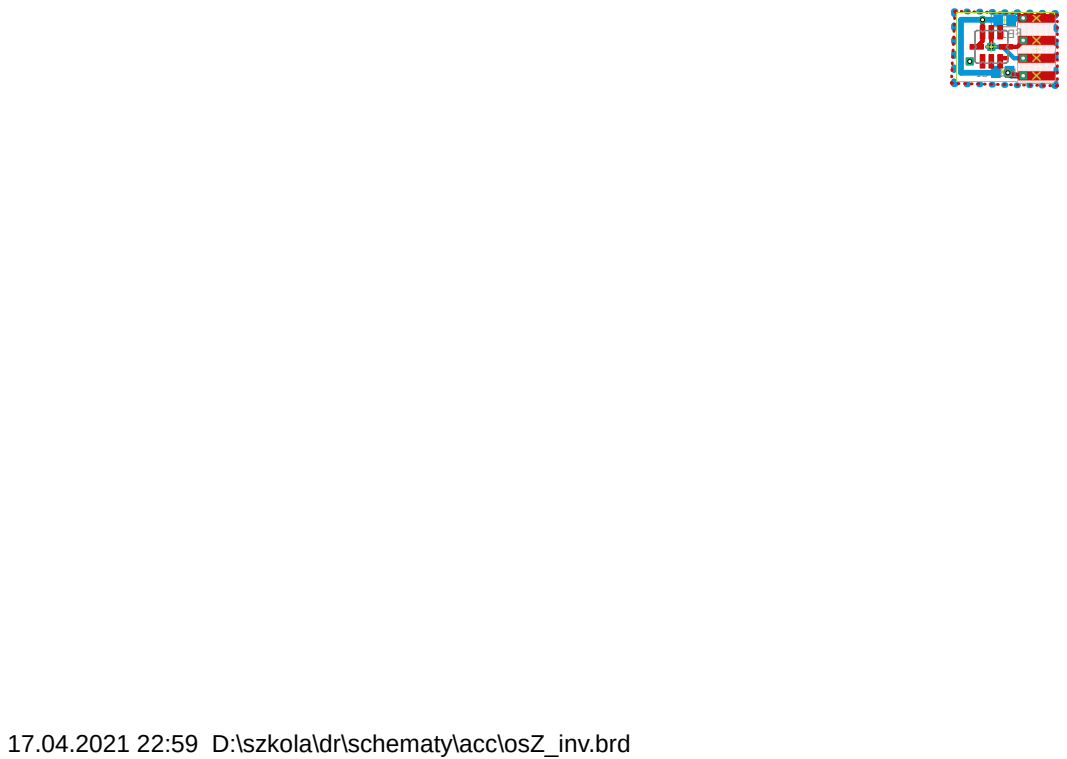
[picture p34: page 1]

17.04.2021 22:59 D:\szkola\dr\schematy\acc\osZ_inv.brd

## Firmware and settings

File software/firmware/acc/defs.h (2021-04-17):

#if !defined(_DEFS_H_)
#define _DEFS_H_

#define FCY 40000000UL
#include <libpic30.h>

#define FULL_SPEED

#define _AUTOPSV	__attribute__((auto_psv))
#define _NOAUTOPSV	__attribute__((no_auto_psv))

//#define LED0	LATBbits.LATB12
//#define LED1	LATBbits.LATB13
//#define LED2	LATBbits.LATB14

#define LED0	LATDbits.LATD3
#define LED1	LATDbits.LATD2
#define LED2	LATDbits.LATD1

#define CS_ENC	LATGbits.LATG9

#define CS_REF1	LATEbits.LATE7
#define CS_REF2	LATEbits.LATE6
#define CS_REF3	LATEbits.LATE5

#define CS_AMP1	LATEbits.LATE2
#define CS_AMP2	LATEbits.LATE3
#define CS_AMP3	LATEbits.LATE4

#define	SDI		PORTGbits.RG7
#define SDO		LATGbits.LATG8
#define SCK		LATGbits.LATG6

#define NEG_SET(x, y) {x = !(y);}

//void __delay32(DWORD cnt);

#endif // _DEFS_H_

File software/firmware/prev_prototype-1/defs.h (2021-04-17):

#if !defined(_DEFS_H_)
#define _DEFS_H_

#define LED0	LATBbits.LATB12
#define LED1	LATBbits.LATB13
#define LED2	LATBbits.LATB14

#define CS_ENC	LATGbits.LATG9
#define CS_REF	LATFbits.LATF3
#define CS_AMP	LATFbits.LATF5

#define	SDI		PORTGbits.RG7
#define SDO		LATGbits.LATG8
#define SCK		LATGbits.LATG6

void __delay32(DWORD cnt);

#endif // _DEFS_H_
